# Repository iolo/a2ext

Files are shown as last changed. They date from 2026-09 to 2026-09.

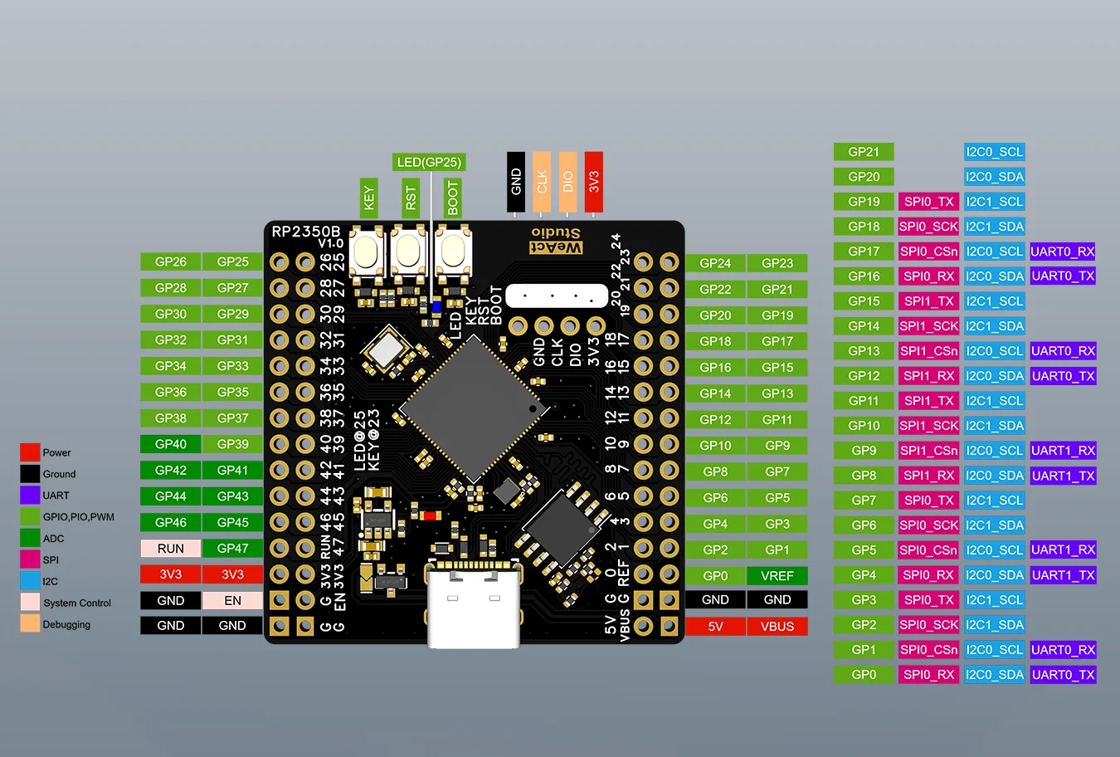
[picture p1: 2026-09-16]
ref/rp2350b-weact.png

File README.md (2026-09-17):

# a2ext

Apple II extension-card prototype built around the **WeAct Studio RP2350B Core
Board V1.0**, with interchangeable VGA and DVI daughterboards. It captures the
full 16-bit address bus, shares a main/auxiliary RAM shadow between firmware
backends, and provides UART and an optional active slot-ROM demo.

**Status: implemented schematic and firmware prototypes; hardware acceptance is
open.** Software tests and all three schematic ERC checks pass. Power sequencing,
bus timing, live capture throughput and monitor operation have not been measured.
DVI and the active demo use experimental 252 MHz clocking, above the RP2350
rating. PCB layout and fabrication files are outside this release.

## Deliverables

| Component | Files |
|---|---|
| Carrier with direct Apple II bus connections | [KiCad project, PDF, BOM and assembly notes](hw/a2ext-carrier/) |
| RGB333 VGA daughterboard | [KiCad project, PDF, BOM and DAC calculations](hw/a2ext-vga/) |
| DVI over HDMI connector | [KiCad project, PDF, BOM and wiring](hw/a2ext-dvi/) |
| Common capture, API and shadow library | [a2ext-lib](fw/a2ext-lib/README.md) |
| Passive/active demonstration | [a2ext-demo](fw/a2ext-demo/README.md) |
| AppleII-VGA renderer port | [a2ext-vga](fw/a2ext-vga/README.md) |
| A2DVI renderer/libdvi port | [a2ext-dvi](fw/a2ext-dvi/README.md) |

[PRD](PRD.md), [implementation plan](PLAN.md), and [progress record](PROGRESS.md)
describe the scope and per-step commits. [GPIO/IDC assignments](hw/pinout.json)
are the shared hardware/firmware pin contract.

## Build and verify

Use Pico SDK/picotool 2.2.0, ARM GCC/newlib and CMake. The active demo additionally
requires ca65/ld65. See [firmware build instructions](fw/README.md) for dependency
revisions, configuration options and flashing.

```sh
cmake -S . -B build/local -DPICO_SDK_PATH=/path/to/pico-sdk \
  -DPICO_TOOLCHAIN_PATH=/path/to/arm-toolchain -DCMAKE_BUILD_TYPE=Release
cmake --build build/local -j4
python3 tools/smoke.py
python3 tools/smoke.py --erc --firmware-from build/local
```

Builds produce `a2ext-demo`, `a2ext-vga` and `a2ext-dvi` ELF/UF2/map files.
The default demo is passive; video targets render host shadow memory at nominal
640x480/60 Hz. `A2EXT_APPLE_MODEL=IIPLUS` selects II/II+ behavior;
`A2EXT_VIDEO_TEST_PATTERN=ON` selects video test patterns;
`A2EXT_DEMO_ACTIVE=ON` opts into the experimental slot responder.

The [verification record](docs/VERIFICATION.md) separates host replay, clean
builds and ERC from unperformed physical tests. Renderer replay writes images
to `build/replay`. [Resource accounting](docs/resources.md) covers PIO, DMA,
clocking, scheduling and SRAM; no full output framebuffer is allocated.

## Hardware preparation and first use

The module has **two 2x15 headers**, not Pico headers. With all power removed,
prepare its GPIO23 button, GPIO25 LED, secondary-memory branch and USB power path:
remove **R16, R19, R14 when fitted, and on-module U2**; leave U7/R13/C23
unpopulated. U2 removal disables USB power; carrier D2 is omitted. Read the
[carrier assembly notes](hw/a2ext-carrier/README.md) before modifying a module;
on-module designators differ from carrier designators.

All 33 host-bus lines connect directly to GPIO2-34, with an optional SYNC jumper.
GPIO40-47 remain on the 3.3 V daughterboard interface. There is no power-off bus
isolation. Slot pin 25 feeds F1/D1 and the module's **5V (H1.2)** input,
labelled `VSYS` on the carrier; **VBUS (H1.1)** is unconnected. USB is data only.
For flashing, remove the card and supply 5 V through a fixture at slot pins
25/26. Do not hot-plug it. The
[power-transition checks](hw/a2ext-carrier/POWER-VALIDATION.md) and
[bench procedure](docs/HARDWARE-VALIDATION.md) remain open.
Use direct daughterboard mating first. The fused slot rail supplies HDMI +5 V.

UART0 is 115200 8N1, 3.3 V, on IDC pins 1 (TX) and 2 (RX), with ground on 16/20.
Send `?` for passive/video diagnostics. Missing slot-7 SYNC does not gate video.
Capture begins before renderer initialization, but it cannot reconstruct earlier
RAM writes. Unknown bank state requires explicit switch initialization and a host
redraw; warm RESET preserves RAM and reacquires switches. The bench guide gives
a repeatable IIe initialization sequence. Active response limitations, including
late replies and reset races, are documented in the library and demo guides.

## Compatibility scope

| Host/output | Implemented software | Validation |
|---|---|---|
| Apple II / II+ | 40-column normal/inverse/flashing text, lores, hires, mixed, pages 1/2 | Host replay and builds; physical not run |
| Apple IIe | Above plus main/aux banking, 80-column, alternate charset, double lores/hires, 80STORE and IOUDIS | Host replay and builds; physical not run |
| VGA | RGB333, 640x480/60, 126 MHz system clock | Replay/build/ERC; DAC/sync/monitor not run |
| DVI | TMDS via PIO1/PWM, 640x480/60, experimental 252 MHz | Replay/build/ERC; signal/clock/monitor not run |
| Active demo | Slot registers/ROM, C800 ownership, UART, IRQ/NMI | Policy/PIO logic/build; physical timing not run |

US enhanced IIe and US II/II+ fonts are bundled. Unenhanced IIe-specific font,
PAL color emulation, Videx/Video7 interfaces, IIc/IIgs, language-card/RamWorks
shadowing, audio, CEC and EDID negotiation are outside the validated scope.
The two video renderers retain their upstream artifact-color palettes.

## Upstream work

This project adapts [a2pico](https://github.com/oliverschmidt/a2pico),
[AppleII-VGA](https://github.com/markadev/AppleII-VGA) through the
[rallepalaveev fork](https://github.com/rallepalaveev/AppleII-VGA), and
[A2DVI-Firmware](https://github.com/ThorstenBr/A2DVI-Firmware), including libdvi.
Original MIT notices are retained alongside the ports. See
[attribution and revisions](docs/ATTRIBUTION.md). Reference trees are kept
separate from the adapted firmware sources.

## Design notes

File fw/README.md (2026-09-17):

# Firmware build and flashing

Three targets share `a2ext-lib`: passive/optional active demo, VGA, and DVI.
These are software-checked prototypes; see [verification](../docs/VERIFICATION.md)
and the open [physical gate](../docs/HARDWARE-VALIDATION.md).

## Dependencies

- Pico SDK **2.2.0**, commit `a1438dff1d38bd9c65dbd693f0e5db4b9ae91779`.
- picotool 2.2.0 for UF2 generation, revision in `dependencies.json`.
- CMake >=3.20, Make or Ninja, ARM GCC/newlib. Validation used GCC 14.2.1.
- ca65/ld65 for `A2EXT_DEMO_ACTIVE=ON`; Python 3 for ROM embedding and checks.
- Host C11 compiler/pthreads for tests; KiCad CLI 10 for schematic checks.

The CMake build rejects a different Pico SDK version. Use the exact dependency
commits in [dependencies.json](dependencies.json) for reproduction. PIO assembly
uses the matching SDK tool. Supply an installed picotool CMake package via
`-Dpicotool_DIR=/path/to/picotool`; otherwise the SDK may download/build its
matching tool. USB stdio is disabled, and UART0 belongs to the a2ext library.
The firmware ports are self-contained and do not build source from `ref/`.

```sh
cmake -S . -B build/local -DPICO_SDK_PATH=/path/to/pico-sdk \
  -DPICO_TOOLCHAIN_PATH=/path/to/arm-toolchain \
  -Dpicotool_DIR=/path/to/picotool -DCMAKE_BUILD_TYPE=Release
cmake --build build/local -j4
```

Run at repository root. The toolchain directory contains `bin/arm-none-eabi-gcc`
and its newlib installation. If the compiler is already on PATH, the explicit
toolchain argument can be omitted. Choose a fresh build directory when changing
SDK/toolchain paths. Outputs are `a2ext-{demo,vga,dvi}.elf`, `.uf2`, and `.elf.map`.

For this workspace's restored toolchain, the verified configuration is:

```sh
cmake -S . -B build/resumed -DPICO_SDK_PATH=/home/iolo/pico-sdk \
  -DPICO_TOOLCHAIN_PATH=/home/iolo/workspace/retro/a2ext/.cache/arm-toolchain/usr \
  -Dpicotool_DIR=/home/iolo/pico-sdk/picotool -DCMAKE_BUILD_TYPE=Release
cmake --build build/resumed -j4
```

## Configuration

| CMake option | Default | Meaning |
|---|---|---|
| `A2EXT_APPLE_MODEL` | `IIE` | `IIE` or `IIPLUS` (also original Apple II); selects banking/font behavior |
| `A2EXT_DEMO_ACTIVE` | `OFF` | Compile 6502 ROM and enable experimental active slot responses; 252 MHz, SRAM execution |
| `A2EXT_VIDEO_TEST_PATTERN` | `OFF` | VGA test chart / DVI color bars while passive capture continues |

VGA/passive demo use 126 MHz. DVI uses 252 MHz to serialize 25.2 MHz pixels;
this exceeds the RP2350 rating and remains unqualified. Firmware does not alter
core voltage. Both video outputs default to 640x480/60 Hz with centered Apple
content. Models are selected explicitly, not auto-detected. See each target's
README for supported features and limitations.

The prepared-module board definition targets RP2350B/ARM and 16 MiB flash. It
omits stock LED/button/SPI/I2C defaults because those pins carry Apple II signals.
Do not substitute the stock WeAct definition. `tools/pinout.py` validates the
header generated from `hw/pinout.json`.

## Verification

```sh
python3 tools/smoke.py
python3 tools/smoke.py --erc --firmware-from build/local
python3 tools/memory_report.py build/local --size-tool /path/to/arm-none-eabi-size
```

The matrix uses fresh build directories and saves logs. It also exercises the
actual renderers on desktop traces, with PPM output under `build/replay`. Tests
never flash the module. UF2 generation is not evidence of hardware operation.

## Flashing procedure

No flashing has been performed in this project session. First complete module
preparation and the fixture power checks. Remove the card from the Apple II
before flashing. USB is data only: on-module U2 and carrier D2 are removed.
Use a current-limited 5 V fixture connected to J1 pin 25 (+5 V) and pin 26 (GND),
with bus signal outputs released. This powers the normal F1/D1/VSYS path.

1. Hold BOOTSEL while applying fixture power (or hold BOOTSEL and pulse module
   RUN with fixture power already on), then release BOOTSEL.
2. Connect USB for data. Confirm the RP2350 boot drive appears; copy exactly one
   selected `.uf2` to it.
   Use the passive demo first, then a video test-pattern build on a fixture.
3. Let the module reboot; verify current draw and released host-bus pins before
   any host connection. UART uses IDC 1/2 at 3.3 V, 115200 8N1; no USB console.
4. After electrical qualification, perform the host/timing tests in the bench
   guide. Do not enable active mode merely because the passive image boots.

To recover an unsuitable firmware image, disconnect the host and repeat BOOTSEL
with a known passive image. Apple /RES does not reset the RP2350; module RUN does.
Archive the ELF, map, UF2 hash, options, dependency revisions and measurements
for each tested hardware configuration.

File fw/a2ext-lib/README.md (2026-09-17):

# a2ext-lib interface

Call `a2ext_init()` once on core 0 before starting capture or other cores. It
releases every Apple II bus pin, initializes UART0 at 115200 8N1, and enables
reset observation. It never configures a default LED or button. Active data
output is disabled by default.

Call capture start/next/stop/stats on one owning core (normally core 1). The
capture engine owns PIO0 SM0, two claimed DMA channels, and DMA IRQ1 on that
core. `a2ext_next_cycle` is nonblocking and returns an atomic address/data/RWB/
select sample. Select booleans mean asserted. Read-cycle data is observational
only; the current sampling window guarantees no claim about CPU read values.

`getaddr/getdata` return fields of the last successfully returned cycle; they
do not consume or read live GPIOs. `has_cycle` is false before the first sample.
Prefer the atomic cycle interface. Getters belong to the capture owner, not
arbitrary concurrent consumers. Watch `stats.epoch`: start, stop, FIFO stalls,
and unread-block overwrite break continuity. Overflow recovery discards queued
samples and resynchronizes on PHI0; shadow users must invalidate their state.

`irq(true)` and `nmi(true)` assert low; false releases the line. The output
latch is always zero. Apple reset assertion releases both interrupt outputs.
These pins connect directly to the host, whose pull-ups complete this interface.

Register reset, UART receive, and optional composite SYNC callbacks on core 0.
Call `a2ext_poll` there regularly. IRQs enqueue events; poll dispatches at most
32 per call. The bounded queue counts dropped events via `callback_drops`.
Callback loss must be reported by the application. Callbacks never run in
capture context, and must not perform long blocking work when rendering video.

SYNC is slot-7 composite sync, not the CPU clock. Registration counts falling
edges; counter 0 or NULL disables it. An absent SYNC signal does not affect
capture or video timing. Reset callbacks receive true on assertion and false
on release. UART receive passes a byte zero-extended to the requested uint32_t
callback argument. `send` blocks until UART TX accepts a byte; do not call it
from the capture/response core.

Enable the experimental responder with `a2ext_slot_enable(handler)` on the
bus core, then call `a2ext_slot_poll()` continuously there. It owns PIO2 SM0
(27 words) and PIO0 SM1 (a separate 3-word delayed sample). The handler sees
selected reads early and writes after the delayed sample. Return true with
`*reply` set to answer a read; false leaves the data bus released. The default
remains passive. Disable releases the data pads before stopping either SM.

`try_putdata` accepts requests only inside an eligible read callback, with
PHI0 and reset high. Acceptance means queued, not acknowledged by the 6502.
PIO matches a 24-bit cycle tag and rejects stale replies. C800 requires prior
local Cnxx selection; CFFF or another slot's Cnxx access releases ownership.
FIFO overflow or early/late address mismatch disables responses and latches
`slot_faulted`; re-enable explicitly to recover. Do not stop a core or PIO with
a debugger while connected to a running host.

This is an experimental response implementation: software tests do not prove
6502 setup/hold timing. Falling PHI0 can race the final enable instructions;
logical release takes up to four PIO cycles after the internally observed
edge, plus input synchronization and board propagation. Reset prevents new
CPU requests but does not asynchronously cancel an already queued reply.
Callbacks may have side effects even when their reply misses the deadline;
protocols needing acknowledged reads need a completion mechanism. Qualify
these limitations with a bus fixture before enabling active mode on a host.

## Optional shadow model

`a2ext_shadow.h` owns 128 KiB RAM plus 16 KiB validity. Select IIe or II/II+
explicitly at initialization. Feed each cycle and capture epoch from the capture
core; do not also apply deferred reset callbacks. /RES is sampled with each
cycle. Reset retains observed RAM but marks switches unknown until accesses
reacquire them. Startup and stream loss similarly require switch reacquisition;
unknown-bank writes are discarded. This can delay a useful display until the
host initializes its switches and redraws. Reading RAM alone cannot recover it.

RAM writes below C000 are tracked. ALTZP controls 0000-01FF; AUXWRITE controls
0200-BFFF except 80STORE's page-1 text and HIRES-dependent graphics overrides.
80STORE suppresses displayed page 2. IIe 80COL/ALTCHAR/IOUDIS/AN3 are tracked; II/II+
ignore these. Language-card RAM, RamWorks, IIc/IIgs extensions, and Videx are
not modeled. IOUDIS must be observed on before AN3 changes DHIRES.
`shadow_byte` reports unknown bytes; `shadow_copy` substitutes zero.
Atomic readers can take a frame copy while capture continues, with possible
tearing. No API claims a coherent host framebuffer snapshot.

Banking reference: [Apple IIe Reference Manual, chapter 4](https://mirrors.apple2.org.za/Apple%20II%20Documentation%20Project/Computers/Apple%20II/Apple%20IIe/Manuals/Apple%20IIe%20Technical%20Reference%20Manual.pdf).

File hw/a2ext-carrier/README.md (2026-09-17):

# a2ext-carrier schematic prototype

Open `a2ext-carrier.kicad_pro` in KiCad 10. Symbols are project-local and embedded
in the schematic. `BOM.csv` lists component values; footprints not yet specified
are deliberate because PCB layout is out of scope. `connections.json` is the
generated connectivity contract, checked against KiCad's exported netlist.

Revision 0.5 uses A4 landscape with 1.524 mm pin names, wire labels, and values;
pin numbers are 1.27 mm and references/notes are 1.778 mm. Symbols and notes
are rearranged for printing at actual size; electrical connections are unchanged.

**Status: schematic draft, not electrically qualified.** ERC checks connectivity,
not bus timing, power sequencing, module thermals, or Apple II compatibility.

## Module and connections

M1 represents both WeAct V1.0 headers. Pin numbers `H1.n` and `H2.n` refer to
the vendor schematic, not arbitrary carrier header numbering. Do not substitute
a Pico 2 or Clintech module. See the module drawing for orientation.

Prepare the module with power disconnected: remove R16 (KEY/GPIO23), R19
(LED/GPIO25), R14 (secondary chip select), and **on-module U2** (the vendor's
unidentified VBUS-to-5V power-path device). Leave secondary memory U7/R13/C23
unpopulated. Removing U2 disconnects USB VBUS from the module supply; do not
bridge its vacated input/output pads. Carrier D2 is removed and M1 H1.1 (VBUS)
is unconnected. Inspect and continuity-test these modifications. USB is for
data only and cannot power the prepared card.

J1 follows the PRD's counter-clockwise slot numbering. /INT and /DMA chains
pass through. Unused negative supplies, +12V, /RDY, /DMA, /INH, and auxiliary
clocks are not connected. JP1 defaults open: close it only when motherboard
documentation confirms composite SYNC on slot 7 pin 19. UART0 and all 13 general
daughterboard GPIOs are on J2. /RES is sensed separately from module RUN.

## Direct bus and power

Revision 0.5 retains direct connections for all 33 bus signals to GPIO2-34,
with JP1 in the optional SYNC path. Wire labels use Apple II signal names
(`A0`, `D0`, `IOSEL_N`, etc.), `UART_TX`/`UART_RX`, and daughterboard names
such as `IDC03_GPIO35`. `_N` means active low; UART direction is from the
carrier's perspective. M1 shows the physical GPIO names and WeAct header
contacts; J2 shows pin functions alongside its contact numbers. Matching
wire labels identify the same electrical net. No bus switches, supervisors,
or BUS_GOOD/BUS_OE_N control circuit remain. GPIO40-47 stay on the 3.3 V
daughterboard interface. Firmware
must drive IRQ/NMI low or release them; the host supplies their pull-ups.

RP2350 fault-tolerant digital inputs support 5 V with IOVDD powered at 3.3 V.
The direct connection provides no protection against a live 5 V bus with an
unpowered module. All operating power comes from the slot supply. Flash with
the card removed from the host, using a 5 V fixture at J1 pins 25/26 and USB
for data only; do not hot-plug the card. Measure startup/shutdown
and brownout behavior using the [power-validation procedure](POWER-VALIDATION.md).

R4 retains the module RUN pull-up. RUN resets M1 but does not disconnect bus
pins; Apple /RES remains a separate input.

The power path is `J1.25 (+5V_SLOT) -> F1 -> D1 -> VSYS -> M1 H1.2`.
The WeAct module labels H1.2 **5V**; it feeds the regulator input and serves the
same function as Pico's VSYS. H1.1 is **VBUS**, and stays unconnected on the
carrier. D1 is retained as reverse-current protection, with its anode toward
F1 and cathode toward VSYS. C9 decouples VSYS. F2 feeds +5V_DB from the fused
slot rail before D1. J2 power pins are outputs, not auxiliary inputs.

Initial allocation: at most 400 mA for carrier/module plus 100 mA for the
daughterboard from the slot branch, subject to the actual host's available
budget and PTC derating. This is a design ceiling, not a measured consumption
or a fuse trip-current guarantee. The module regulator's part number/current
rating is unspecified in the vendor drawing; reserve the 3.3 V daughterboard
pin for light loads until that rating and module temperature are established.

## Checks and outstanding work

```sh
python3 tools/pinout.py
python3 tools/check_schematics.py a2ext-carrier
```

Run from the repository root. Regenerate explicitly with
`python3 tools/schematics.py carrier`; review changes before replacing manual
edits. Export the PDF with `kicad-cli sch export pdf`.

Physical release requires power-transition, supply/thermal, and bus timing
measurements. ERC does not establish the WeAct module's supply ramp behavior.

Sources: vendor module files in `ref/WeActStudio.RP2350BCoreBoard/HDK/`,
[RP2350 datasheet](https://datasheets.raspberrypi.com/rp2350/rp2350-datasheet.pdf).

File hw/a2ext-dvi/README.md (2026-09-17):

# a2ext-dvi

Revision 0.2 uses A4 landscape with enlarged text: 1.524 mm pin names,
wire labels and values, 1.27 mm pin numbers, and 1.778 mm references/notes.
The revised layout preserves all electrical connections.

Passive DVI video daughterboard using an HDMI Type A connector and the PRD's
270 ohm series resistor network. Open the KiCad 10 project; symbols are local.
The abstract SH pin represents all connector shell contacts. Confirm the exact
HDMI-SWM-19 mechanical drawing and pad numbering before any PCB work.

| Lane | Positive GPIO / IDC | Negative GPIO / IDC | HDMI contacts |
|---|---|---|---|
| D0 | 36 / 4 | 37 / 5 | 7 / 9 |
| D1 | 38 / 6 | 39 / 7 | 4 / 6 |
| D2 | 40 / 8 | 41 / 9 | 1 / 3 |
| Clock | 42 / 10 | 43 / 11 | 10 / 12 |

Each conductor has a 270 ohm, 1% resistor. Shields, pin 17, shell, and both IDC
ground contacts share GND. Pin 18 receives the carrier's fused +5V_DB supply;
there is no additional series diode drop on this board. C1 decouples that rail.
UART, RUN, 3.3 V power, GPIO35/44-47, DDC, HPD, CEC, and utility are unused.

The bundled libdvi program uses the lower GPIO for the positive conductor when
`invert_diffpairs=false`. Use PIO1 base 16 and 64-bit mask helpers. Its clock
generator uses the shared PWM slice for even/odd GPIO42/43. This is the
reference's resistor-driven signaling approach, not a claim of HDMI compliance.

Initially use direct carrier mating. No ribbon cable length is qualified.
Validate a fixed 640x480 timing mode, pair polarity, eye/edge quality, connector
+5 V, and lock on multiple monitors with a real board. No EDID negotiation or
hotplug handling is implemented by this schematic. Carrier power comes from
the slot input (or an off-host fixture at that input); USB is data only.

Validation so far: ERC and named-net export checks. Firmware and physical
TMDS tests are pending. From the repository root:

```sh
python3 tools/schematics.py dvi
python3 tools/check_schematics.py a2ext-dvi
```

References: `ref/A2DVI` v5.x hardware and
`ref/A2DVI-Firmware/libraries/libdvi/dvi_serialiser.{c,pio}`.

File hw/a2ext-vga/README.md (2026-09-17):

# a2ext-vga

Revision 0.2 uses A4 landscape with enlarged text: 1.524 mm pin names,
wire labels and values, 1.27 mm pin numbers, and 1.778 mm references/notes.
The revised layout preserves all electrical connections.

KiCad 10 schematic and project-local symbols for a passive 9-bit VGA
daughterboard. J1 follows the common IDC20 pinout. J2 is a female DE-15HD;
its abstract SH pin represents the connector shell. Select the connector's
exact shell/mounting pad numbers when a PCB is designed.

GPIO35-43 are R0-R2, G0-G2, B0-B2. GPIO44/45 are HSYNC/VSYNC. UART, GPIO46/47,
power, and RUN are unused. Both IDC ground contacts connect to VGA grounds and
shell. DDC, ID, and pin 9 power are unconnected, as specified in the PRD.

Each color has 2 kohm, 1 kohm, and 500 ohm resistors for bits 0, 1, and 2.
Use 1% tolerance. With a 75 ohm monitor load and ideal 3.3 V GPIO outputs:

`Vout = 3.3 * (b0/2000 + b1/1000 + b2/500) / (1/75 + 1/2000 + 1/1000 + 1/500)`

The eight nominal levels are 0, 0.0980, 0.1960, 0.2941, 0.3921, 0.4901,
0.5881, and 0.6861 V. Full-scale current is 9.15 mA per color; the MSB GPIO
supplies about 5.23 mA. Firmware pad drive settings must support this load;
start with 8 mA drive and verify voltage and edge quality on hardware. Real
GPIO output impedance changes these ideal values.

R10/R11 are 47 ohm series resistors on sync. Use direct mating to the carrier
for initial qualification; an IDC ribbon cable has no validated length.

Validation: KiCad ERC and exported named-net checks; physical levels and
640x480 timing are not yet tested. Run from the repository root:

```sh
python3 tools/schematics.py vga
python3 tools/check_schematics.py a2ext-vga
```

Design references: PRD resistor network and the bundled A2VGA2 schematic.

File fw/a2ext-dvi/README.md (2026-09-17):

# DVI firmware

Port of the bundled A2DVI-Firmware renderer and its libdvi serializer. Original
MIT notices remain in the source, LICENSE, and libdvi/LICENSE. Text, lores,
hires, mixed, page switching, 80-column, double-lores and double-hires paths
consume frame copies from the common main/aux shadow model.

PIO1 base 16 drives the three TMDS data pairs, PWM GPIO42/43 drives the clock,
and six DMA channels feed the serializer through DMA IRQ0 on core 0. Core 1
owns passive bus capture. Output is 640x480 at 60 Hz, with 560x384 Apple content
and 48-line top/bottom borders. Eight 3840-byte TMDS buffers are allocated;
there is no full RGB framebuffer. No SYNC input or EDID negotiation is needed.

252 MHz is experimental and above the RP2350's rated frequency. Firmware does
not raise core voltage. Build success is not evidence of physical stability,
monitor lock, or reliable capture under rendering load. Qualification requires
the carrier power gate, timing measurements and sustained host/monitor tests.

`A2EXT_APPLE_MODEL=IIE` (default) uses an enhanced US font and IIe banking;
`IIPLUS` uses II/II+ behavior. `A2EXT_VIDEO_TEST_PATTERN=ON` produces color bars
while capture continues. UART `?` reports capture status. Menus, Videx, Video7,
IIgs, buttons/LEDs, custom configuration registers and alternate video timings
from the reference are outside this port's supported interface.

Adaptations: high-GPIO 64-bit masks, PIO base 16, carrier pair polarity, normal
Pico SDK RAM sections instead of the upstream custom linker-copy scheme,
384-line content window, fixed configuration, common capture/shadow, and
finite-frame entry point. TMDS patterns retain the upstream color choices;
VGA and DVI artifact colors need not be numerically identical.

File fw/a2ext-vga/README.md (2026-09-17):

# VGA firmware

Port of the bundled rallepalaveev AppleII-VGA renderer (MIT, see LICENSE).
Uses shared passive capture/shadow on core 1 and frame snapshots/rendering on
core 0. PIO1 base 16 generates RGB333 and sync; DMA IRQ0 feeds eight scanline
buffers. Capture uses PIO0 and DMA IRQ1. No full RGB framebuffer is allocated.

Default output is 640x480 at 60 Hz, centered 560x384 Apple content. Supports
40-column text, lores, hires, mixed mode and page selection; IIe adds 80-column,
alternate charset, double lores and double hires. Defaults to enhanced US IIe
font; `A2EXT_APPLE_MODEL=IIPLUS` selects II/II+ font and bank behavior. Videx,
Video7 control extensions and PAL color emulation are not enabled.

`A2EXT_VIDEO_TEST_PATTERN=ON` renders the upstream test chart while capture
continues. UART `?` reports capture losses and known soft switches. Initial
unobserved bytes render as zero; reset/stream loss may require host switch
initialization and redraw. Physical timing, DAC levels, sustained throughput,
and display correctness are not yet qualified.

Port changes: GPIO35-45 mapping/base 16, RGB channel bit reversal at DMA
submission (including precomputed hires patterns), valid OUT count for nine
pins, 8 mA DAC drive, shared shadow snapshots and finite frame entry point.

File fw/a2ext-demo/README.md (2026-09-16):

# Demo

Default builds passively count bus cycles. UART0 is 115200 8N1 on IDC pins
1/2 with 3.3 V levels. Send `?` for capture/overflow/callback-drop counters;
reset transitions are reported. No daughterboard or slot-7 SYNC is required.

`-DA2EXT_DEMO_ACTIVE=ON` builds the experimental a2pico-derived slot ROM and
register demo. Requires ca65/ld65; runs from SRAM at 252 MHz (above the RP2350
rating). Qualify carrier power and response timing before use. Read the
limitations in `../a2ext-lib/README.md`. No hardware operation is claimed.

The 4096-byte ROM contains seven slot pages and C800 code. After qualification,
`PR#n` enters the terminal demo in slot n. Register offset 0 transfers a byte;
offset 1 reports bit 6 RX-ready and bit 7 TX-ready. Writing offset 1 releases
IRQ/NMI. UART ESC asserts IRQ and Ctrl-N asserts NMI. The bounded inter-core
FIFOs can drop UART input when full; this is a demonstration, not a reliable
serial adapter. Reset releases IRQ/NMI and C800 ownership.

`firmware.S` and `firmware.cfg` derive from Oliver Schmidt's a2pico demo;
original MIT notices are preserved. The banner is adapted to a2ext.

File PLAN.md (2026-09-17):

# a2ext implementation plan

**Execution rule:** After each numbered implementation step, update `PROGRESS.md`
with changes, validation results, and blockers, then commit that step's changes
together with the progress update. Include only task-related changes. Record
partial or blocked work honestly; a commit does not imply completion.

## Summary and agreed scope

Build a WeAct Studio RP2350B Core Board carrier, VGA and DVI daughterboard
schematics, a shared firmware library, and demo/VGA/DVI firmware.

Target Apple II/II+ and IIe, including IIe auxiliary-memory video modes. Deliver
KiCad schematics, BOMs, documentation, and reproducible firmware builds. PCB
routing and fabrication outputs are excluded; physical validation remains a
separately recorded acceptance gate.

Use the bundled reference projects as porting sources, preserving attribution
and licenses. Keep their source trees unchanged.

Approved revision (2026-09-17): use direct bus connections, following the
RP2350 reference designs. Remove the CB3T switches and their supervisors,
BUS_GOOD/OE control, and local support components. This supersedes the earlier
isolation refinement. Keep power-transition measurements and document installed
slot-only power operation. Revision 0.3 removes D2 and leaves module VBUS NC;
slot power feeds F1/D1 and H1.2 (5V, equivalent to VSYS). On-module U2 stays
removed to disable USB power. Off-host flashing uses fixture power and USB data.

## 1. Resolve the hardware and firmware contracts

1. Update the PRD to identify the WeAct module and correct its connector
   description using the supplied schematic and dimensions.
2. Correct RX on IDC pin 2, `TMDS` spelling, `uint8_t`, and the DVI framebuffer
   description. Add the demo firmware to the expected outputs.
3. Record removal of the module's GPIO23 button connection and GPIO25 LED load
   through R16/R19, as approved. Verify these designators against the actual
   module revision. Leave optional secondary flash/PSRAM unpopulated because
   its chip select shares GPIO0.
4. Establish this GPIO assignment:

   | Signals | GPIOs |
   |---|---|
   | UART TX / RX | 0 / 1 |
   | A0-A15 | 2-17 |
   | D0-D7 | 18-25 |
   | RWB | 26 |
   | /DEVSEL, /IOSEL, /IOSTRB | 27, 28, 29 |
   | PHI0, /RES | 30, 31 |
   | /IRQ, /NMI, optional composite SYNC | 32, 33, 34 |
   | Daughterboard general-purpose signals | 35-47 |

5. Define IDC pins 1/2 as TX/RX; pins 3-15 as GPIO35-47; pin 16 as an additional
   ground; pin 17 as 3.3 V; pin 18 as module RUN; pins 19/20 as protected
   5 V/ground. This provides 13 additional GPIOs, accounting for all 33 Apple II
   bus signals.
6. Allocate PIO0 to bus capture with GPIO base 0 and PIO1 to video with GPIO
   base 16. Reserve PIO2 for active slot responses. Validate instruction,
   state-machine, DMA, and timing budgets before completing the schematics.
   RP2350 PIO blocks address 32 GPIOs at a time through these base selections.

**Exit criterion:** one reviewed pin/resource table shared by schematics,
firmware constants, and documentation.

## 2. Complete the three hardware designs

7. Create the carrier under `hw/a2ext-carrier`:
   - Use project-local symbols for the WeAct module and correctly numbered
     Apple II slot.
   - Preserve interrupt/DMA chain connections and specified unused slot pins.
   - Keep Apple /RES sensing separate from module RUN.
   - Implement /IRQ and /NMI as assert-low/release outputs.
   - Document slot-only power, USB power disconnection, reverse-current protection,
     decoupling, and daughterboard power budgets.
8. Validate startup, shutdown and brownout behavior for the approved direct-bus
   circuit. Document the powered-IOVDD requirement and USB operating restrictions.
   Keep ADC-capable GPIO40-47 exclusively on the 3.3 V daughterboard interface.
   Do not declare hardware ready if sequencing remains unresolved.
9. Create the VGA schematic under `hw/a2ext-vga`:
   - Assign R0-R2 to GPIO35-37, G0-G2 to GPIO38-40, B0-B2 to GPIO41-43.
   - Assign HSYNC/VSYNC to GPIO44/45.
   - Implement the specified resistor DACs and sync resistors; calculate
     output levels into a 75 ohm termination.
10. Create the DVI schematic under `hw/a2ext-dvi`:
    - Assign D0 +/- to GPIO36/37, D1 +/- to GPIO38/39, D2 +/- to GPIO40/41,
      and clock +/- to GPIO42/43.
    - Use the reference's resistor-driven TMDS circuit and verify polarity
      against serializer configuration.
    - Keep audio, CEC, and EDID negotiation outside v1.
    - Document direct daughterboard mating as the baseline; ribbon-cable
      operation requires separate signal-integrity validation.

**Exit criterion:** all three schematics pass ERC with reviewed exceptions and
include BOMs, exported PDFs, connector tables, and assembly notes.

## 3. Implement the shared library and demo

11. Establish CMake/Pico SDK builds and a WeAct board definition. Pin dependency
    revisions and produce ELF, UF2, and map files for all three firmware
    targets. Place the common library in `fw/a2ext-lib`.
12. Implement passive capture first:
    - Sample full addresses, data, RWB, and slot selects using PHI0-qualified
      timing.
    - Transfer captured cycles through DMA into bounded buffers.
    - Expose overflow counters and mark shadow state invalid after capture
      loss.
    - Keep timing-critical capture independent of rendering and UART callbacks.
13. Define the library interfaces:
    - Preserve requested API names and correct their types.
    - Add an atomic bus-cycle interface containing address, data, direction,
      and selection flags; define getaddr/getdata against the same latched
      cycle.
    - Restrict putdata to an eligible, current slot-read transaction; reject
      late responses and release the bus at cycle end.
    - Default to passive mode; explicitly enable slot response handling.
    - Use UART0 at 115200, 8N1. Retain the requested receive callback signature,
      with the byte in its low eight bits.
    - Define SYNC callbacks as counting composite-sync pulses, not PHI0 cycles.
      Missing slot-7 SYNC must not prevent operation.
14. Add active slot responses and port the a2pico demo into `fw/a2ext-demo`.
    Exercise slot registers/ROM, reset reporting, UART, IRQ, and NMI. Enforce
    C800 ownership and CFFF release; /IOSTRB alone must not enable data output.
15. Implement optional shared video shadowing: main/auxiliary memory tracking,
    video soft switches, page selection, and reset state. Begin capture early,
    document incomplete initial shadow contents, and avoid clearing shadow RAM
    merely because Apple RESET occurs.

**Exit criterion:** demo builds and automated bus traces validate capture,
slot ownership, and shadow-state behavior.

## 4. Port VGA, then DVI

16. Port AppleII-VGA rendering into `fw/a2ext-vga`, replacing its bus interface
    with the common library. Start with test patterns, then add 40-column text,
    lores, hires, mixed mode, page switching, and IIe extended modes.
17. Port A2DVI-Firmware into `fw/a2ext-dvi`, retaining its renderer and PIO/libdvi
    serializer approach. Adapt GPIO-base handling and remove
    transceiver-specific capture code. Use the shared shadow model.
18. Default both outputs to 640x480 at approximately 60 Hz. Give bus capture
    priority over rendering and diagnostics. Document and validate the DVI
    clock configuration, including any above-rated operation inherited from
    the reference.

**Exit criterion:** both backends render the same replayed Apple II video states
without capture overflow or resource conflicts.

## 5. Verify and package

19. Automate clean builds, pin-allocation checks, KiCad ERC, and trace-based tests
    covering full-address capture, consecutive cycles, reset, overflow
    recovery, selected/unselected reads, late responses, C800 ownership,
    II/II+ video modes, IIe banking, 80-column, double-lores, double-hires,
    missing SYNC, and simultaneous capture/rendering load.
20. Publish hardware validation procedures for power sequencing, bus loading,
    response timing, interrupt release, VGA voltage/timing, and DVI stability.
21. Complete the README with build/flashing instructions, module modifications,
    compatibility matrix, resource allocation, upstream attribution, and
    validation results. Clearly distinguish automated verification from
    measurements requiring assembled hardware.

## Technical references

- Local module schematic, dimensions, and pinout:
  `ref/WeActStudio.RP2350BCoreBoard/HDK/`.
- [RP2350 datasheet](https://datasheets.raspberrypi.com/rp2350/rp2350-datasheet.pdf):
  PIO GPIOBASE, electrical ratings, and GPIO pad types.
- [Raspberry Pi 5 V tolerance qualification](https://www.raspberrypi.com/news/rp2350-a4-rp2354-and-a-new-hacking-challenge/):
  IOVDD must remain powered when 5 V is applied to GPIO.

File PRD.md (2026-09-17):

# a2ext

GOAL: General purpose Apple II Extension Card using the WeAct Studio RP2350B Core Board and daughter boards.

- Adapt a2pico's general hardware concept to RP2350B.
- Snoop all address range(A0..A15) like AppleII-VGA and A2DVI.
- Utilize 48 GPIOs of RP2350B instead of complex multiplexing for insufficient GPIO of RP2040/RP2350.
- Delegate specific functions to daughter boards, with a 20pin IDC connector for daughter boards rather than a single monolithic design.

EXPECTED OUTPUT:

1. a2ext-carrier kicad schematic and docs in hw/a2ext-carrier
2. a2ext-vga kicad schematic and docs in hw/a2ext-vga
3. a2ext-dvi kicad schematic and docs in hw/a2ext-dvi
4. a2ext-lib common library for a2ext-carrier daughter board firmware in fw/a2ext-lib
5. a2ext-vga firmware in fw/a2ext-vga
6. a2ext-dvi firmware in fw/a2ext-dvi
7. a2ext-demo firmware in fw/a2ext-demo

## a2ext-carrier

The carrier accepts the WeAct Studio RP2350B Core Board V1.0 documented in
`ref/WeActStudio.RP2350BCoreBoard/HDK/`. Use its two 2x15, 2.54 mm pitch
headers (60 contacts total), not Pico/Pico 2 headers. These expose GPIO0..47
alongside power, reference, enable, and RUN contacts. The module schematic
specifies a 41.4 mm x 41.1 mm board; use the supplied dimension drawing and
STEP model for header placement and USB/button access.

Initial compatibility: Apple II/II+ and IIe, including IIe auxiliary-memory
video modes. Deliver schematics, BOMs, documentation, and firmware; PCB layout
and fabrication files are outside this release.

### Required WeAct module preparation

Use the V1.0 schematic as the reference and check the populated module revision
before changing components. With all power removed:

- Remove R16 (0 ohm) to disconnect GPIO23 from SW3 (KEY), its 5.1 kohm pull-up
  R18, and its associated protection/capacitor network. GPIO23 will carry D5.
- Remove R19 (5.1 kohm) to disconnect the U8 user LED from GPIO25. GPIO25 will
  carry D7. The separate power LED is unaffected.
- Leave U7 (secondary flash/PSRAM) and its optional R13/C23 unpopulated; remove
  R14 (0 ohm), if fitted, to isolate GPIO0 from the FLASH2_SS branch. UART TX
  must not toggle a secondary memory chip select or inherit its pull-up.
- Remove on-module U2 (the vendor's unidentified VBUS-to-5V power-path device).
  This disables USB power. Carrier D2 is omitted and module H1.1 (VBUS) is NC.
  Slot pin 25 feeds F1/D1 and module H1.2 (marked 5V, the VSYS-equivalent input).
  D1 is retained for reverse-current protection; USB is data only.
- Check for opens across the removed resistor pads and shorts to neighboring
  pads before installation. Pressing KEY must no longer connect GPIO23 to GND;
  GPIO25 must no longer connect to U8 through R19.

BOOTSEL, RUN/reset, primary flash, USB data (with external power), and SWD remain usable. The firmware must
not initialize GPIO25 as an LED or GPIO23 as a button. Never fit an unprepared
module: KEY could otherwise pull an Apple II data line low.

```
Apple II Peripheral Slot <--(50pin Edge Connector)--> RP2350B <--(20pin IDC Connector)--> daughter board
```

1. snoops Apple II BUS signals with RP2350B PIO state machines
2. (optional) makes a shadow copy of RAM
3. provides a 20pin IDC connector for daughter boards.

RP2350B digital fault-tolerant pads accept 5 V only with IOVDD powered to
3.3 V; ADC-capable pads do not share that rating. Approved revision 0.2 connects
the bus directly, removing the earlier isolation/control circuit. Use slot power
exclusively. For off-host USB flashing, power the card from a fixture at slot
pins 25/26; USB does not supply power.
Preserve full parallel address/data wiring; do not multiplex the Apple II bus
to save GPIOs. Power-transition measurements remain open.

Required Apple II bus signals required by RP2350B:

- D0..D7 : read/write
- A0..A15 : read only
- RWB : read only (1 for CPU read, 0 for CPU write)
- /DEVSEL : read only (0 on CPU access $C0n0..$C0nF; n=slot+8=9..F for slots 1..7)
- /IOSEL : read only (0 on CPU access $Cn00..$CnFF; N=slot=1..7)
- /IOSTRB : read only (0 on CPU access $C800..$CFFF)
- /RES : read only
- /IRQ : write only
- /NMI : write only
- PHI0 : read only, bus-cycle timing (slot pin 40)
- SYNC : read only, composite video sync (slot 7 pin 19; motherboard-dependent)

## wiring

### Apple II slot (50-pin edge connector) <-> WeAct RP2350B module (two 2x15 headers)

The slot symbol uses counter-clockwise numbering, with pin 1 at the upper
left: 1–25 run down the left side and 26–50 run back up the right side.
Opposing contacts are 1/50, 2/49, through 25/26, matching the
[slot reference](ref/a2slot.png) rotated 180 degrees.

```text
 1 /IOSEL  ┌─────────┐  50 +12V
 2 A0      │         │  49 D0
 3 A1      │         │  48 D1
   ...     │         │     ...
24 /DMAOUT │         │  27 /DMAIN
25 +5V     └─────────┘  26 GND
```

* Pin assignments are defined in [hw/pinout.json](hw/pinout.json).
  Address/data/control inputs GPIO2..31 fit PIO GPIO base 0.
  All 33 Apple II bus connections use GPIO2..34; GPIO40..47 are reserved
  for the 3.3 V daughterboard interface, not 5 V Apple II signals.

- 1 /IOSEL --> GPIO 28
- 2 A0 --> GPIO 2
- 3 A1 --> GPIO 3
- 4 A2 --> GPIO 4
- 5 A3 --> GPIO 5
- 6 A4 --> GPIO 6
- 7 A5 --> GPIO 7
- 8 A6 --> GPIO 8
- 9 A7 --> GPIO 9
- 10 A8 --> GPIO 10
- 11 A9 --> GPIO 11
- 12 A10 --> GPIO 12
- 13 A11 --> GPIO 13
- 14 A12 --> GPIO 14
- 15 A13 --> GPIO 15
- 16 A14 --> GPIO 16
- 17 A15 --> GPIO 17
- 18 RWB --> GPIO 26
- 19 SYNC --> GPIO 34 (slot 7 only; motherboard-dependent)
- 20 /IOSTRB - GPIO 29
- 21 /RDY - N/C
- 22 /DMA - N/C
- 23 /INTOUT - 28 /INTIN
- 24 /DMAOUT - 27 /DMAIN
- 25 +5V_SLOT -- F1 / D1 (SS14) --> VSYS --> module H1.2 (5V); H1.1 (VBUS) N/C
- 26 GND --- GND; 26 GND --(100n cap.)-- 25 +5V
- 27 /DMAIN - 24 /DMAOUT
- 28 /INTIN - 23 /INTOUT
- 29 /NMI <--> GPIO 33 (assert low/release; host pull-up)
- 30 /IRQ <--> GPIO 32 (assert low/release; host pull-up)
- 31 /RES --> GPIO 31 (input only)
- 32 /INH - N/C
- 33 -12V - N/C
- 34 -5V - N/C
- 35 COLORREF - N/C
- 36 7M - N/C
- 37 Q3 - N/C
- 38 PH1 - N/C
- 39 USER1 - N/C
- 40 PHI0 --> GPIO 30
- 41 /DEVSEL --> GPIO 27
- 42 D7 <--> GPIO 25
- 43 D6 <--> GPIO 24
- 44 D5 <--> GPIO 23
- 45 D4 <--> GPIO 22
- 46 D3 <--> GPIO 21
- 47 D2 <--> GPIO 20
- 48 D1 <--> GPIO 19
- 49 D0 <--> GPIO 18
- 50 +12V - N/C

### 20pin IDC Connector <-> RP2350B

The 2x10 IDC header uses odd/even numbering: pins 1 and 2 are opposite
each other, followed by 3 and 4, through 19 and 20. TX/RX are on pins 1/2, VCC/GND are on pins 19/20.

```
   +-------+
TX | 1   2 | RX
   | 3   4 |
   | 5   6 |
   ...
5V | 19 20 | GND
   +-------+
```

The UART signals are named from the carrier's perspective (3.3 V logic).
Pin 18 resets the module through RUN and is separate from Apple II /RES.
Daughterboards may assert RUN low with an open-drain output; never drive it high.

| IDC pin | Carrier signal | GPIO |
|---|---|---|
| 1 | TX | 0 |
| 2 | RX | 1 |
| 3 | GPIO35 | 35 |
| 4 | GPIO36 | 36 |
| 5 | GPIO37 | 37 |
| 6 | GPIO38 | 38 |
| 7 | GPIO39 | 39 |
| 8 | GPIO40 | 40 |
| 9 | GPIO41 | 41 |
| 10 | GPIO42 | 42 |
| 11 | GPIO43 | 43 |
| 12 | GPIO44 | 44 |
| 13 | GPIO45 | 45 |
| 14 | GPIO46 | 46 |
| 15 | GPIO47 | 47 |
| 16 | GND | — |
| 17 | +3V3 output | — |
| 18 | RUN (active low) | — |
| 19 | protected +5V_DB output | — |
| 20 | GND | — |

There are 13 general-purpose daughterboard GPIOs in addition to TX/RX. GPIO46/47
are spare for VGA, and GPIO35/44..47 are spare for DVI. All daughterboard signal
pins use 3.3 V logic; in particular, GPIO40..47 are not 5 V-tolerant pads.
Use direct mating initially; ribbon-cable operation requires separate validation.

## a2ext-vga

a2ext-carrier daughterboard for VGA video output.

- used with a2ext-vga firmware.
- based on [A2VGA2 by rallepalaveev](https://github.com/rallepalaveev/AppleII-VGA/tree/main/A2VGA2),
  which is based on [AppleII-VGA](https://github.com/markadev/AppleII-VGA)

1. Read red, green, blue bits from a2ext-carrier IDC20 connector.
2. Convert to analog RGB using 3-bit weighted resistor DACs.
3. Output VGA signals through a female VGA connector.

### VGA (DE-15HD female) <--> a2ext-carrier 20pin IDC Connector

- 1 R <--(500 Ohm resistor, red bit 2)-- IDC 5 / GPIO37 R2
- 1 R <--(1K Ohm resistor, red bit 1)-- IDC 4 / GPIO36 R1
- 1 R <--(2K Ohm resistor, red bit 0)-- IDC 3 / GPIO35 R0
- 2 G <--(500 Ohm resistor, green bit 2)-- IDC 8 / GPIO40 G2
- 2 G <--(1K Ohm resistor, green bit 1)-- IDC 7 / GPIO39 G1
- 2 G <--(2K Ohm resistor, green bit 0)-- IDC 6 / GPIO38 G0
- 3 B <--(500 Ohm resistor, blue bit 2)-- IDC 11 / GPIO43 B2
- 3 B <--(1K Ohm resistor, blue bit 1)-- IDC 10 / GPIO42 B1
- 3 B <--(2K Ohm resistor, blue bit 0)-- IDC 9 / GPIO41 B0
- 4 N/C
- 5 GND -- 20 GND
- 6 GND -- 20 GND
- 7 GND -- 20 GND
- 8 GND -- 20 GND
- 9 N/C
- 10 GND - 20 GND
- 11 N/C
- 12 N/C
- 13 HSYNC <--(47 Ohm resistor)- IDC 12 / GPIO44 HSYNC
- 14 VSYNC <--(47 Ohm resistor)- IDC 13 / GPIO45 VSYNC
- 15 N/C
- Connector shell -- 20 GND

## a2ext-dvi

a2ext-carrier daughterboard for DVI video over an HDMI Type A connector.

- used with a2ext-dvi firmware.
- based on [A2DVI v5.x](https://github.com/rallepalaveev/a2dvi/tree/main/v5.x).

1. Read TMDS bit stream(encoded by a2ext-dvi firmware) from a2ext-carrier IDC20 connector.
2. Write to HDMI Type A connector.

### HDMI-SWM-19 <--> a2ext-carrier 20pin IDC Connector

- 1 D2+ --(270 Ohm resistor)-- IDC 8 / GPIO40 D2_P
- 2 GND -- 20 GND
- 3 D2- --(270 Ohm resistor)-- IDC 9 / GPIO41 D2_N
- 4 D1+ --(270 Ohm resistor)-- IDC 6 / GPIO38 D1_P
- 5 GND -- 20 GND
- 6 D1- --(270 Ohm resistor)-- IDC 7 / GPIO39 D1_N
- 7 D0+ --(270 Ohm resistor)-- IDC 4 / GPIO36 D0_P
- 8 GND -- 20 GND
- 9 D0- --(270 Ohm resistor)-- IDC 5 / GPIO37 D0_N
- 10 CLK+ -- (270 Ohm resistor)-- IDC 10 / GPIO42 CLK_P
- 11 GND -- 20 GND
- 12 CLK- --(270 Ohm resistor)-- IDC 11 / GPIO43 CLK_N
- 13 N/C
- 14 N/C
- 15 N/C
- 16 N/C
- 17 GND -- 20 GND
- 18 +5V_DB (slot 5V through F1/F2, before D1) -- IDC 19
- 19 N/C
- Connector shell -- 20 GND

## a2ext-lib

common library for a2ext-carrier daughter boards firmwares

- based on [a2pico](https://github.com/oliverschmidt/a2pico).
- but full address range(A0..A15) is snooped,
- and 48 GPIOs of RP2350B can be used instead of complex multiplexing for insufficient GPIO of RP2040/RP2350.

### files

- a2ext.c
- a2ext.h
- a2ext.pio : PIO program for snooping Apple II bus signals.
- and convenient stuff from a2pico to build RP2350B firmwares.

### functions(apis)

- void a2ext_init()
- uint16_t a2ext_getaddr() : read A0..A15(GPIO2..17)
- uint8_t a2ext_getdata() : read D0..D7(GPIO18..25)
- void a2ext_putdata(uint8_t data) : write D0..D7(GPIO18..25)
- void a2ext_irq(bool on) : on/off /IRQ(GPIO32)
- void a2ext_nmi(bool on) : on/off /NMI(GPIO33)
- void a2ext_on_reset(void(*reset_handler)(bool on)) : register reset_handler for /RES (GPIO31)
- void a2ext_on_sync(void(*sync_handler)(void), uint32_t counter) : register sync_handler for SYNC(GPIO34)
- void a2ext_send(uint8_t data) : transmit one byte on TX (GPIO 0; IDC20 pin 1)
- void a2ext_on_receive(void(*receive_handler)(uint32_t data)) : register receive_handler for RX(GPIO 1; IDC20 pin2)

## a2ext-vga firmware

firmware for a2ext-carrier with a2ext-vga daughter board

- based on [AppleII-VGA](https://github.com/markadev/AppleII-VGA),
- modified for a2ext-carrier.
- physical snooping of Apple II bus signals is done by a2ext-carrier with a2ext-lib.

1. Read shadowed video framebuffer and I/O space(Apple II soft-switches)
2. Update VGA framebuffer
3. Write pixels, HSYNC, VSYNC into IDC20 connector.

## a2ext-dvi firmware

firmware for a2ext-carrier with a2ext-dvi daughter board

- based on [A2DVI-Firmware](https://github.com/ThorstenBr/A2DVI-Firmware),
- modified for a2ext-carrier.
- physical snooping of Apple II bus signals is done by a2ext-carrier with a2ext-lib.

1. Read shadowed video framebuffer and I/O space(Apple II soft-switches)
2. Render the DVI output scanlines and encode TMDS data
3. Write TMDS signals to IDC20 connector.

## a2ext-demo firmware

firmware for a2ext-carrier without daughter board

- based on [a2pico demo](https://github.com/oliverschmidt/a2pico/tree/main/demo),
- modified for a2ext-carrier.
- physical snooping of Apple II bus signals is done by a2ext-carrier with a2ext-lib.

## References

- [WeAct Studio RP2350B Core Board](ref/WeActStudio.RP2350BCoreBoard/README.md)
- [Module schematic](ref/WeActStudio.RP2350BCoreBoard/HDK/RP2350B_SCH.pdf)
- [Module dimensions](ref/WeActStudio.RP2350BCoreBoard/HDK/尺寸图.pdf)

- [AppleII-VGA](https://github.com/markadev/AppleII-VGA) original by markadev
- [AppleII-VGA-rallepalaveev](https://github.com/rallepalaveev/AppleII-VGA) for RP2350B by rallepalaveev
- [A2DVI](https://github.com/rallepalaveev/a2dvi)
- [A2DVI-Firmware](https://github.com/ThorstenBr/A2DVI-Firmware)
- [A2C_DVI_Prototype](https://github.com/FarLeftLane/A2C_DVI_Prototype)
- [a2pico](https://github.com/oliverschmidt/a2pico)
- [Raspberry Pi Pico C SDK](https://www.raspberrypi.com/documentation/pico-sdk/)

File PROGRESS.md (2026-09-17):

# a2ext progress

Follow [PLAN.md](PLAN.md). Update this file and commit after every numbered step.
Only mark a step complete when its stated checks pass. Separate documentary,
automated, and physical validation.

## Status

- Steps 1-5 complete (documentary/automated checks).
- Step 6 resource allocation and passive/video assembly checks complete;
  active-response implementation/timing proof deferred to step 14.
- Step 7 schematic revised to slot-powered direct bus with signal labels
  (revision 0.5, A4 landscape); step 8 procedure updated, physical
  acceptance blocked on hardware and a measurement fixture.
- Steps 9-10 daughterboard schematics complete (revision 0.2, A4 landscape;
  automated checks).
- Steps 11-13 build setup, passive capture, and API definition complete (software checks).
- Step 14 implemented and software-checked; physical active-response timing open.
- Step 15 shared shadow model complete (host traces).
- Step 16 VGA port builds and replay passes; physical display acceptance pending.
- Step 17 DVI port builds and replay passes; physical display acceptance pending.
- Step 18 clocks, priorities and RAM budgets checked; runtime timing open.
- Step 19 automated software/ERC checks pass; physical coverage remains open.
- Steps 20-21 validation procedures, build/flashing docs and attribution complete.
- Initial software/design deliverables are committed; the direct-bus revision
  is recorded below. Physical acceptance is still open.
- Hardware acceptance: not tested; no assembled hardware available in this session.

## Work log

### All schematics — larger type and A4 landscape — 2026-09-18

- Reflowed carrier, VGA, and DVI onto one A4 landscape sheet each. Increased
  pin names/net labels/values from 1.0 to 1.524 mm, pin numbers to 1.27 mm,
  references and notes to 1.778 mm, and headings to 2.032 mm.
- Moved carrier IDC20 below the module, grouped its power components, and
  compacted the daughterboard resistor grids. Labels face outward on all
  sheets; notes fit clear of the drawing borders and title blocks.
- Regenerated schematics, local libraries, and PDFs (carrier 0.5, VGA/DVI 0.2).
  Compared every named net's endpoints with the pre-layout snapshot: all
  58/17/18 nets and electrical connections are unchanged.
- Validation: all three ERC/connectivity checks pass with zero violations;
  PDF page dimensions confirm A4 landscape (841.896 x 595.296 points), and
  rendered pages were visually reviewed. `git diff --check` passes. No firmware
  changes or physical tests were required for this presentation update.

### Carrier revision 0.4 — readable wire labels — 2026-09-17

- Replaced GP-only carrier nets with Apple II signal names, UART_TX/UART_RX,
  and IDCnn_GPIOxx daughterboard labels. Retained `_N` for active-low signals
  and documented UART direction. M1 preserves physical GPIO/header numbering;
  power pins clarify 5V/VSYS and USB VBUS. J2 now shows contact functions.
- Placed carrier net labels outward from symbols to avoid pin-number overlap,
  and regenerated the schematic, local symbols, PDF, and connectivity contract.
- Validation: compared net endpoint sets against revision 0.3; all 58 net
  connections are unchanged. Carrier ERC and connectivity checks pass with
  zero violations. Visually reviewed the PDF; no firmware change or new
  physical measurements.

### Carrier revision 0.3 — slot-only power — 2026-09-17

- User specified slot power into VSYS and no USB power, retaining D1 as
  protection. Verified the WeAct reference: H1.2 is marked 5V and feeds its
  regulator input (the VSYS function); H1.1 is USB VBUS.
- Existing slot input was already on H1.2. Renamed that rail VSYS, removed
  carrier D2, and left H1.1 NC. Retained F1/D1 and on-module U2 removal so
  USB cannot supply the module. F2 still feeds the daughterboard before D1.
- Regenerated schematic/PDF/BOM/net contract and updated power/flashing docs:
  off-host flashing uses a 5 V fixture at slot pins 25/26 plus USB data.
- Added independent netlist checks for slot/F1/D1/VSYS routing, D1 polarity,
  disconnected VBUS, and absence of D2. Physical power and USB enumeration
  tests remain NOT_RUN; firmware and GPIO assignments are unchanged.
- Validation: carrier ERC has zero violations, all 58 named-net checks and
  the GPIO pin-contract check pass, and `git diff --check` passes. Reviewed
  the exported schematic PDF against the vendor power/header drawing.

### Carrier revision 0.2 — direct bus — 2026-09-17

- User requested removal of the CB3T switches and their supporting circuit,
  superseding the isolation design recorded in steps 7-8 below.
- Removed carrier U1-U7, Q1, R1-R3, C1-C7, and BUS_GOOD/BUS_OE_N. All 33
  host signals now connect directly to GPIO2-34, retaining the optional SYNC
  jumper. R4, the existing power paths, and firmware pin assignments remain.
- Regenerated schematic, PDF, BOM, local symbols, and net contract. Compacted
  the carrier from A2 to A3 and updated independent slot/module connectivity
  checks, project documentation, and TODO.md.
- Updated operating assumptions to installed slot power and USB flashing/power
  only with the card removed from the host. Replaced switch-specific power
  tests with direct-bus supply-transition checks; physical results stay NOT_RUN.
- Validation: `python3 tools/smoke.py --erc` passes, including host regressions,
  both renderer replays/models, all three ERCs (zero violations), and direct
  connectivity checks (carrier 59 named nets). `git diff --check` passes.
  Firmware code/pin mapping did not change; the clean build matrix passed in
  the preceding status review. No new flashing or physical measurements.

### Planning baseline — 2026-09-17

- Saved the agreed 21-step implementation plan, including the per-step progress
  update and commit rule.
- Confirmed the WeAct reference module is present and KiCad CLI/CMake are
  installed. ARM GCC and Ninja are not on PATH; investigate before step 11.
- The user's staged `.gitmodules` and WeAct submodule addition predate this work;
  preserve those changes and exclude them from task commits unless requested.
- Validation: inspected repository status and local module reference paths.
- Blockers: none for starting documentation; hardware power sequencing and
  physical qualification remain explicit later gates.

### Step 1 — module and connector contract

- Updated PRD to target WeAct RP2350B Core Board V1.0, two 2x15 headers,
  60 contacts, and the module's 41.4 x 41.1 mm outline.
- Recorded II/II+/IIe compatibility and schematic-only hardware deliverables.
- Validation: compared the supplied schematic, pinout image, and dimension PDF;
  confirmed both headers number 1-30. No hardware measurements performed.
- Blockers: none for this step; physical module revision must match the reference.

### Step 2 — PRD corrections and complete deliverable list

- Corrected IDC RX, TMDS spelling, the data return type, UART description, and
  DVI rendering description. Numbered all seven outputs and included the demo.
- Validation: inspected the PRD diff; `git diff --check` passes.
- Blockers: none.

### Step 3 — WeAct module preparation

- Added powered-off preparation and continuity checks for R16 (KEY/D5), R19
  (LED/D7), and the optional secondary-memory branch on GPIO0.
- Also require R14 removal when fitted, avoiding the unused FLASH2_SS branch
  and its optional pull-up on UART TX. Keep U7/R13/C23 unpopulated.
- Validation: visually inspected the rendered vendor schematic, not only text
  extraction; R16/R19/R14 connections match the documented preparation.
- Physical module revision and resistor removal are not verified in this
  session; these are assembly prerequisites, not claimed physical work.

### Step 4 — GPIO contract

- Filled all Apple II GPIO assignments and added PHI0 to the required signals.
- Added `hw/pinout.json` as the pin-allocation source and a generated firmware
  header. `tools/pinout.py` checks uniqueness, slot/address/data ordering,
  PIO range, open-drain interrupt declarations, and exclusion of ADC pads
  from the 5 V bus.
- Validation: generator and subsequent read-only check pass; 33 bus + 2 UART +
  13 daughterboard GPIOs cover GPIO0-47 exactly; `git diff --check` passes.
- Blockers: electrical qualification remains pending; this is a logical map.

### Step 5 — daughterboard connector contract

- Assigned all IDC20 contacts, both video mappings, a second ground, 3.3 V,
  protected 5 V, and RUN. Distinguished module reset from Apple II reset.
- Extended the source pin map and generated header with VGA/DVI pins. Validate
  all 20 IDC contacts and adjacent TMDS pairs; the clock uses an even/odd pair
  to share a PWM slice with the reference serializer.
- Validation: regeneration, pin-contract check, and whitespace check pass.
- Blockers: protected power implementation and physical interface validation
  remain for hardware steps; no daughterboard has been tested.

### Step 6 — PIO, DMA, timing, and memory budgets

- Assigned separate PIO blocks and DMA IRQs; documented 126 MHz passive/VGA
  and experimental 252 MHz DVI clocking, buffer/memory budgets, and high-GPIO
  SDK requirements. Added the passive-capture PIO source.
- Validation: built pioasm from Pico SDK 2.2.0 in /tmp; assembled the capture
  program (3 words), bundled VGA programs (9+8+11 = 28 words), and bundled
  non-debug DVI serializer (2 words). Each fits its assigned PIO instruction
  store. Up to 8/16 DMA channels are reserved for capture plus DVI.
- Active response has a separate 32-word reservation but no assembled design
  or timing proof yet. Physical capture timing is also unverified. These
  limitations are explicit in `docs/resources.md`, not marked as test passes.
- User approved power-off bus isolation where required; updated PLAN/PRD.
- Blockers: none for daughterboard schematics; carrier isolation circuit still
  needs detailed electrical review in steps 7-8.

### Step 7 — carrier schematic draft

- Created a self-contained KiCad carrier project, local symbols, BOM, PDF,
  net contract, generator, and assembly/power documentation.
- Added five CB3T3245 bidirectional isolation/translation switches, dual rail
  supervisors, default-off OE control, separate RUN and Apple reset, optional
  slot-7 SYNC jumper, and explicit fused slot/USB power paths.
- Extended module preparation to remove the unidentified on-module U2 power
  path; carrier D2 restores USB power with a known diode connection.
- Validation: KiCad 10 ERC has zero violations; exported netlist verifies all
  48 module GPIO contacts, 33 switched bus paths, IDC pins, and chain links.
  Visually inspected the schematic PDF. No physical measurements performed.
- Blockers: module regulator rating, brownout timing, and host signal loading
  remain unqualified; this is a schematic prototype, not a fabrication release.

### Step 8 — power-sequencing gate

- Documented the isolation ratings, supervisor thresholds, undefined ramp
  regions, module-part uncertainties, and an explicit power-source/brownout
  measurement matrix in `hw/a2ext-carrier/POWER-VALIDATION.md`.
- Removed KiCad's per-user `.kicad_prl` state from tracking and added generated
  build/cache ignores.
- Validation: manufacturer datasheet review and the earlier ERC/net checks;
  no physical qualification is claimed.
- Blocker: no assembled carrier, identified module regulator, or scope fixture
  is available. Keep this gate open while independent steps continue.

### Step 9 — VGA daughterboard

- Added the VGA KiCad project, local symbols, BOM, PDF, and connectivity
  contract with 9 DAC resistors and two sync resistors.
- Documented nominal 75-ohm DAC levels (0-0.6861 V), per-pin loading, grounding,
  and the direct-mating baseline.
- Validation: zero ERC violations and exported netlist checks; ideal DAC
  calculation checked. Physical signal levels/timing remain untested.
- Blockers: physical acceptance requires a built board, scope, and monitor.

### Step 10 — DVI daughterboard

- Added the HDMI Type A schematic, project-local symbols, BOM, PDF, and
  connectivity contract; all four TMDS pairs use 270-ohm series resistors.
- Documented pair polarity, clock PWM pairing, GPIO-base/mask changes required
  by libdvi, fused pin-18 supply, unused interfaces, and direct mating.
- Validation: zero ERC violations and exported netlist checks; compared
  positive/negative mapping with the reference serializer instructions.
- Blockers: no physical TMDS/monitor tests; abstract connector shell pin must
  be mapped to the chosen part if PCB layout is later undertaken.

### Step 11 — reproducible firmware build setup

- Added CMake targets for demo/VGA/DVI, shared-library build rules, prepared
  WeAct board definition, dependency revisions, and build instructions.
- Initial targets only initialize bus pins as inputs; they do not yet capture,
  respond to slot reads, or generate video. Default LED/button pins are absent.
- Validation: built all three ELF/UF2/map sets using Pico SDK/picotool 2.2.0 and
  ARM GCC 14.2.1/newlib. Compiler packages were extracted under /tmp without
  changing system packages; build artifacts stay in ignored `build/`.
- The SDK warns that TinyUSB is absent; USB stdio is explicitly disabled and
  all targets built successfully. No physical flashing was performed.
- Blockers: none for software implementation; the hardware gate remains open.

### Step 12 — passive DMA bus capture

- Added chained DMA capture into two 1024-word blocks, atomic cycle decoding,
  FIFO-stall/overwrite detection, stream epochs, and resynchronization. Demo
  now consumes the passive capture stream; video targets remain bring-up code.
- Capturing, polling, stopping, and statistics access belong to the same core;
  its DMA IRQ1 owns completion handling. No UART/render callback runs there.
- Validation: all three targets rebuild successfully. Host tests cover every
  16-bit address, data/select decoding, ordered block consumption, repeated
  wrap, and rejection when DMA would overwrite an unread or partial block.
- On resume, /tmp dependencies were gone. Reused the matching SDK at
  `/home/iolo/pico-sdk`, restored ARM packages under ignored `.cache/`, and
  created `build/resumed`. The SDK now has TinyUSB, still disabled for stdio.
- Blockers: physical PIO sampling, DMA throughput, and electrical qualification
  remain untested; host queue tests do not emulate the RP2350 DMA engine.

### Step 13 — common library API

- Added latched address/data getters, open-drain IRQ/NMI helpers, UART0 byte
  transport, and deferred reset/receive/composite-SYNC callbacks. Reset releases
  interrupt outputs; callback queue overflow is observable.
- Documented core ownership, callback dispatch limits, SYNC counting, capture
  epochs, and read-data limitations. `try_putdata` still rejects all output
  until the bounded active response path is implemented in step 14.
- Validation: all three targets compile/link with warnings treated as errors;
  capture decoding/queue regression tests still pass. GPIO/UART behavior has
  not been tested on hardware.
- Blockers: active response implementation and physical timing proof remain.

### Step 14 — experimental slot responder and a2pico demo

- Added an opt-in 27-word PIO responder with per-cycle tags, C800 ownership,
  CFFF release, delayed write sampling, and fail-closed FIFO/mismatch faults.
  Ported the MIT a2pico 6502 ROM and UART/register/IRQ/NMI demo. Default remains
  passive; active builds explicitly use experimental 252 MHz and SRAM code.
- Validation: active and passive firmware builds, host slot-policy regression,
  and an instruction-level PIO test pass. The latter sweeps reply enqueue
  phases, rejects stale/zero tags, checks wrap, and checks bounded release;
  it does not model synchronizers, CPU latency, or electrical timing.
- Limitations: no physical response deadline proof. Final enable can race a
  falling edge (up to four PIO cycles to release, plus synchronization), reset
  does not cancel an already queued PIO reply, and callback side effects are
  not acknowledged by successful CPU sampling. Active mode is experimental.

### Step 15 — shared video shadow

- Added 64 KiB main/aux banks with byte validity, II/II+ versus IIe selection,
  video switches, ALTZP/AUXWRITE/80STORE precedence, and capture-epoch loss
  invalidation. Read cycles never populate RAM from unqualified read data.
- Extended passive samples to include /RES in the same 32-bit DMA word, so
  reset handling follows captured bus order rather than delayed callbacks.
  Warm reset retains RAM/validity and conservatively reacquires switches;
  writes with unknown bank selection are ignored until selection is known.
- Cross-core readers use atomic bytes and validity; frame copies may tear but
  avoid undefined concurrent accesses. I/O, ROM, language-card and expansion
  banking are explicitly outside the RAM shadow contract.
- Validation: host traces pass for bank precedence, 40/80-column and graphics
  switches, reset retention, unknown initial contents, and capture loss.
  Three firmware targets rebuild; capture and slot regressions pass.

### Step 16 — VGA renderer and output port

- Ported the bundled AppleII-VGA text/lores/hires/double-mode renderer, fonts,
  scanline DMA and 28-word PIO programs with MIT attribution. Shared capture
  begins on core 1 before renderer initialization; frame copies isolate the
  renderer from concurrent shadow writes. Added IIe/II+ and test-pattern builds.
- Corrected PIO1 GPIO base, nine-pin OUT setup and RGB bit order, including
  precomputed artifact-color tables. Output remains 640x480 with centered
  560x384 content; model-specific font selection is explicit.
- Validation: all firmware targets compile/link with -Werror. Host renderer
  replay is scheduled in step 19; physical sync/color/throughput checks remain
  open. Added 48 KiB frame-copy storage beyond the original memory estimate;
  final linker-size accounting is step 18 work.

### Step 17 — A2DVI renderer and serializer port

- Retained A2DVI's text/lores/hires/double-mode renderers, TMDS palettes and
  libdvi PIO/DMA serializer with licenses. Adapted high-pin masks, PIO1 base 16,
  RAM sections, pair polarity, model/font selection and shared frame copies.
- Removed upstream debug/status-row demand from the scanline consumer; it now
  displays 384 content lines centered in 480. Eight TMDS buffers use 30 KiB.
  No original transceiver capture, menus, LED/button GPIOs or custom flash
  configuration code runs in this target.
- Validation: all three firmware targets compile/link with -Werror. Renderer
  replay is step 19 work; hardware DVI/capture throughput is not measured.
  The required 252 MHz remains explicitly experimental with no voltage change.

### Step 18 — clock, priority and memory integration

- Fixed both outputs at nominal 640x480/60 Hz (25.2 MHz pixels, 800x525 total).
  Capture remains 126 MHz across VGA/DVI system clocks, with a dedicated core,
  high-priority DMA/IRQ and SRAM hot paths. UART diagnostics are bounded and
  nonblocking; DVI exposes missed-scanline count.
- Added ELF SRAM accounting including frame copies and a separate DVI runtime
  buffer/queue allowance. Current VGA total is 232,332 bytes; DVI conservative
  total is 288,060 bytes, within 520 KiB. No full RGB framebuffer is allocated.
- Validation: all three Release builds pass, clock/divider arithmetic reviewed,
  memory report passes. PLL/timing/overclock stability and simultaneous live
  capture/render throughput remain physical acceptance tests, not build claims.

### Step 19 — automated checks and renderer replay

- Added one-command host/pin/ERC verification and clean firmware matrices for
  IIe, II/II+ with active demo, and video patterns. All nine ELF/UF2/map sets
  build, and SRAM budgets pass. All three schematics retain zero ERC violations.
- Replayed real VGA/DVI renderer sources into host pixel sinks with bounds/UB
  sanitizers. Checked dimensions, page/80STORE selection, mixed text rows,
  double modes and matching normal/inverse/flashing/alternate text in both
  host models. Saved reproducible PPM artifacts under ignored build/replay.
- Fixed DVI double-hires signed shifts, II/II+ character-ROM flash handling and
  flash-phase agreement. Added IOUDIS gating after inspecting the Apple IIe
  Technical Reference Manual table 2-10. Retained conservative reset recovery.
- Concurrent desktop test passes 1,572,864 decoded writes with frame snapshots,
  reset and capture-loss invalidation. It does not benchmark target DMA.
- Detailed coverage/limitations are in docs/VERIFICATION.md. Physical missing
  SYNC, UART/interrupt behavior, response timing and live video/capture load
  tests cannot run without hardware; those acceptance items remain open.

### Step 20 — physical validation procedure

- Published fixture-first assembly/power, passive capture/loading, active timing,
  IRQ/NMI/reset/UART/SYNC, video levels/monitor stability and simultaneous-load
  procedures with measurable acceptance conditions and an evidence worksheet.
- Documented explicit IIe switch initialization/redraw for conservative shadow
  acquisition and the unresolved active-response edge/reset races.
- Validation: reviewed against implemented pin/resource/API contracts and the
  existing power gate. Every physical worksheet entry remains NOT_RUN; no board,
  instrument reading, flashing, monitor result or live host test is claimed.

### Step 21 — documentation and handoff

- Replaced the placeholder README with deliverable links, build/check workflow,
  compatibility matrix, module preparation, initialization behavior, attribution
  and explicit physical limits. Expanded firmware setup/options/flashing and
  recovery instructions; included the verified local toolchain configuration.
- Resolved obsolete PRD power/pull-up placeholders to match the schematics and
  updated the plan's power gate wording to the approved isolation design.
- Validation: reviewed local documentation links and repository diff; final
  source builds and software checks passed in step 19. No flashing performed.
- Remaining acceptance: step 8 power qualification, active response edge/reset
  races and setup/hold timing, target capture/render load, UART/interrupt/SYNC,
  VGA levels and DVI stability. The measurement worksheet records all as NOT_RUN.
  Completion of documentation does not close these physical gates.

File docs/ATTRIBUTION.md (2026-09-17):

# Upstream attribution

The `ref/` repositories remain unmodified by the implementation. Adapted source
is copied under `fw/` so builds do not depend on local changes in a reference
checkout. Exact upstream revisions are in `fw/dependencies.json`.

| Source | Adapted material | Preserved notices |
|---|---|---|
| Oliver Schmidt, a2pico | Demo 6502 ROM/linker layout and slot-terminal concept | MIT headers in demo source; `ref/a2pico/LICENSE` |
| Mark Aikens / David Kuder, AppleII-VGA via rallepalaveev | VGA renderers, RGB tables, fonts, PIO and scanline DMA | `fw/a2ext-vga/LICENSE` |
| Mark Aikens / David Kuder / Thorsten Brehm, A2DVI-Firmware | DVI renderers, fonts, TMDS patterns and library variant | `fw/a2ext-dvi/LICENSE` and source headers |
| Luke Wren / libdvi contributors | TMDS PIO serializer, DMA/queue and timing machinery, as bundled with A2DVI | `fw/a2ext-dvi/libdvi/LICENSE` |
| WeAct Studio | RP2350B Core Board V1.0 schematic, pinout and mechanical references | Vendor files under `ref/WeActStudio.RP2350BCoreBoard` |
| Raspberry Pi | Pico SDK/picotool build and peripheral APIs | External dependencies retain their own notices |

New integration includes the shared GPIO contract, direct-bus carrier and power
schematics, passive DMA capture, tagged experimental responses, shadow model,
frame adapters and verification tools. Port modifications are described in each
firmware README. No claim of upstream hardware endorsement or certification is
made. The original license texts travel with the adapted sources.

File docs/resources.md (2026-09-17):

# RP2350B resource and timing contract

Pin assignments originate in `hw/pinout.json`; run `python3 tools/pinout.py`
to check the generated firmware header. Use Pico SDK 2.2.0 (commit
`a1438dff1d38bd9c65dbd693f0e5db4b9ae91779`) for the initial implementation.

## Resource allocation

| Function | PIO/base | State machines | Program words | DMA channels |
|---|---|---|---|---|
| Passive bus capture | PIO0 / 0 | SM0 | 3 of 32 | 2 reserved for alternating blocks |
| VGA (exclusive with DVI) | PIO1 / 16 | SM0-2 | 28 of 32 from reference | 1 |
| DVI (exclusive with VGA) | PIO1 / 16 | SM0-2 | 2 shared words at origin 0 | 6 (3 data, 3 control) |
| Active slot responder | PIO2 / 0 | SM0 | 27 of 32 | CPU FIFO service |
| Active delayed write sample | PIO0 / 0 | SM1 | 3 additional words | CPU FIFO service |

The passive and video programs can coexist without shared instruction memory,
state machines, or pins. The active responder assembles to 27 words; its instruction-level regression
checks cycle tags and release logic, but physical response timing is unproven.
The RP2350 has 16 DMA channels; reserve at most 8 for capture plus DVI. Claim
channels through the SDK, not hard-coded channel numbers. Use DMA IRQ0 for
video and IRQ1 for capture; the bundled video implementations use exclusive
handlers. GPIO/UART handlers and deferred callbacks run on core 0; core 1 owns
bus consumption and optional active responses. Renderer work runs on core 0.

Initialize each PIO's GPIO base before adding programs. GPIO35-45 video outputs
are in PIO1's GPIO16-47 window. Use the SDK's 64-bit mask APIs and `1ull << pin`
for high GPIOs; the reference DVI helpers' `3u << data_pins` are not valid for
these assignments. SDK pin configuration functions accept physical GPIO numbers;
PIO instruction immediate GPIO operands must respect the PIO base.

DVI clock GPIO42/43 is an even/odd pair on one PWM slice; reserve that slice
for the pixel clock. PIO produces the three TMDS data pairs. HSTX is not used:
its fixed GPIO range conflicts with the bus assignment. UART0 uses GPIO0/1;
never configure the module's default LED/button GPIOs.

## Capture timing and capacity

`a2ext_capture` waits for PHI0 low then high and samples GPIO2-31 after the
29-cycle delay. At a 126 MHz SM clock, the sample is approximately 32 SM clocks
(254 ns) after the observed external edge, allowing for input synchronization.
This follows the direct-capture reference's write-data sampling window; scope
measurements must account for direct wiring, bus loading, and host model.
Do not disable input synchronizers until measured timing justifies it.

The 30-bit word is shifted left and autopushed: bits 0-15 address, 16-23 data,
24 RWB, 25 /DEVSEL, 26 /IOSEL, 27 /IOSTRB. Bit 28 is PHI0 and bit 29 is /RES, preserving reset order with the stream.
Select bits are active low. Capture
every PHI0 CPU cycle, not only slot-selected traffic. Read-cycle data is not
guaranteed valid at this sample instant; writes and read-side soft-switch
addresses are sufficient for the initial shadow model.

At a design budget of 1.1 million cycles/s, DMA traffic is 4.4 MB/s. Reserve
two 1024-word blocks (8 KiB), allowing about 0.93 ms per block. Joined RX FIFO
holds 8 words, only about 7.3 us at that rate: block DMA must chain without a
CPU rearm gap. FIFO stalls and unconsumed block reuse must both invalidate
shadow state; neither is recoverable by silently continuing the old stream.

Use a 126 MHz capture SM clock: divider 1 for 126 MHz demo/VGA and divider 2
for a 252 MHz DVI system clock. DVI's 252 MHz clock is above the RP2350's
150 MHz rating and remains an explicit experimental configuration requiring
physical qualification; do not raise the core voltage without a separate
documented rating review. If the clock cannot be established, remain passive
and report failure rather than changing timing silently.

## Memory envelope and remaining timing gate

Reserve 128 KiB for main/auxiliary shadow memory, 16 KiB for byte-validity maps,
8 KiB for capture blocks, and at most 32 KiB for video scanline/TMDS buffers.
Keep code, stacks, queues, and other data within the remaining SRAM verified
by linker maps; do not allocate a full 640x480 RGB framebuffer. Firmware
builds must report actual RAM usage rather than treating this budget as proof.

The delayed passive capture cannot serve slot reads on its own. PIO2 needs an
earlier request path, an explicit deadline, and a cycle identity so late CPU
responses cannot drive the following cycle. Gate outputs with read/selection,
PHI0, reset, and C800 ownership. There is no physical response-timing claim
until step 14's implementation and the hardware procedure pass.

Sources: bundled `ref/AppleII-VGA-rallepalaveev/pico/vga.pio`,
`ref/A2DVI-Firmware/libraries/libdvi/dvi_serialiser.pio` and `dvi.c`, and the
[RP2350 datasheet](https://datasheets.raspberrypi.com/rp2350/rp2350-datasheet.pdf).

## Implemented clocks and scheduling

Both backends use a 25.2 MHz pixel clock, 800 pixels/line and 525 lines/frame:
31.5 kHz horizontal and exactly 60 Hz nominal vertical. VGA system/capture
clock is 126 MHz; RGB PIO runs at 50.4 MHz and sync PIO at 3.15 MHz. DVI system
and serializer run at 252 MHz, PWM divides by 10, and capture SM divides by 2.
All clock changes happen before UART/capture initialization. No voltage override
is used. DVI and the opt-in active demo exceed the rated 150 MHz; their actual
operating margin is unmeasured. PLL lock/build success is not qualification.

Capture DMA uses high-priority channels and IRQ1 at highest priority on core 1.
Video DMA/IRQ0 and UART/event dispatch stay on core 0. Capture polling, statistics
and shadow-write hot paths reside in SRAM. Frame copies add 48 KiB to the initial
memory budget; renderers operate on these copies without blocking capture.
UART status output sends at most 16 immediately writable bytes per frame, so a
slow UART cannot stall the renderer. The DVI status includes missed scanlines.
No video output is synchronized to optional slot-7 SYNC.

`tools/memory_report.py BUILD --size-tool /path/to/arm-none-eabi-size` checks
allocated SRAM sections and a separate DVI runtime-allocation allowance.
Release build at step 18 (bytes, including minimum heap and both stacks):

| Target | Allocated SRAM | Additional runtime allowance | Remaining of 520 KiB |
|---|---:|---:|---:|
| Passive demo | 17,688 | 0 | 514,792 |
| VGA | 232,332 | 0 | 300,148 |
| DVI | 256,316 | 31,744 | 244,420 |

The DVI allowance covers 30,720 bytes of TMDS data plus 1 KiB for queues and
allocation overhead; minimum heap already counted above makes this conservative.
Map sizes vary with toolchain/configuration. Stack high-water marks, worst-case
capture service time and live DMA/render throughput still require measurement.

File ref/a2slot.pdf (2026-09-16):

# Apple II Slot

## 50-pin double-sided edge connector expansion slot used in Apple II, II+, IIe, and IIGS computers, carrying the

6502 address, data, and clock buses.

1 2 3 4 5 6 7 8 9 10 11 12 13 14 15 16 17 18 19 20 21 22 23 24 25

50 49 48 47 46 45 44 43 42 41 40 39 38 37 36 35 34 33 32 31 30 29 28 27 26

Apple II - 50 pin female bus

connector

The Apple II peripheral expansion slot is a proprietary 50-pin double-sided edge connector (25 contacts per side, 100 mil pitch, 200 mil row spacing) introduced with the Apple II in 1977 and retained, with minor signal changes, through the Apple IIe and Apple IIGS. It exposes the 6502-family bus directly: a 16-bit address bus (A0–A15), an 8-bit bidirectional data bus (D0–D7), phase clocks, interrupt and DMA daisy-chain lines, and four power rails (+5 V, −5 V, +12 V, −12 V). Up to seven slots are provided in the IIe (Slots 1–7); the IIGS retains the same seven slots with full backward compatibility. Several pin assignments dier between models — most notably pins 19, 35, and 39 — so card designers must account for the target platform.

Pin | Name | Direction | Description
1 | /IOSEL | OUT | I/O Select. Active when page $Cn gets accessed. N.C. on slot 0
2 | A0 | IN/OUT | Buered address bus
3 | A1 | IN/OUT | Buered address bus
4 | A2 | IN/OUT | Buered address bus
5 | A3 | IN/OUT | Buered address bus
6 | A4 | IN/OUT | Buered address bus
7 | A5 | IN/OUT | Buered address bus
8 | A6 | IN/OUT | Buered address bus
9 | A7 | IN/OUT | Buered address bus
Apple II Slot · AllPinouts | https://allpinouts.org/pinouts/connectors/buses/apple-ii-slot/
1 of 5 | 9/16/26, 10:00

Pin | Name | Direction | Description
10 | A8 | IN/OUT | Buered address bus
11 | A9 | IN/OUT | Buered address bus
12 | A10 | IN/OUT | Buered address bus
13 | A11 | IN/OUT | Buered address bus
14 | A12 | IN/OUT | Buered address bus
15 | A13 | IN/OUT | Buered address bus
16 | A14 | IN/OUT | Buered address bus
17 | A15 | IN/OUT | Buered address bus
18 | R/W | IN/OUT | Buered Read/Write signal.
19 | SYNC | OUT | Only Slot 7. SYNC from Video Generator. Not on Rev 0 Boards. Testpin on Slot 1 for //e
20 | /IOSTRB | OUT | I/O Strobe. Active when $C800 and $CFFF gets accessed
21 | /RDY | IN | Activation during Phi1 will halt the CPU, with the address bus holding the last address
22 | /DMA | IN | Activation disables the 6502"s address bus and halts the CPU
23 | /INTOUT | IN | Daisy-chained interrupt output to lower priority devices
24 | /DMAOUT | IN | Daisy-chained DMA output to lower priority devices
25 | +5V | | +5 Volt power supply. Max. 500mA for ALL peripheral boards
26 | GND | | System electrical ground
27 | /DMAIN | OUT | Daisy-chained DMA input from higher priority devices
28 | /INTIN | OUT | Daisy-chained interrupt input from higher priority devices
29 | /NMI | IN | Non-Maskable Interrupt. Monitor ROM starts interrupt handling routine at location $3FB
30 | /IRQ | IN | Interrupt ReQuest. Monitor starts the routine pointed to by $3FE/F

Pin | Name | Direction | Description
31 | /RES | IN | RESet
32 | /INH | IN | INHibits the on board ROMs ($D000-$FFFF)
33 | -12V | | -12 Volt power supply. Max. 200mA for ALL peripheral boards
34 | -5V | | -5 Volt power supply. Max. 200mA for ALL peripheral boards
35 | COLORREF | OUT | Only Slot 7. 3.5 MHz Video COLOR REF. Not on Rev 0 Boards. Testpin on Slot 1 for //e. M2B0 on A2gs
36 | 7M | OUT | 7Mhz clock
37 | Q3 | OUT | 2Mhz asymetrical clock
38 | PHI1 | OUT | 1 MHz phase 1 clock
39 | Various | OUT | USER1 on A2: Disable adressdecode. 65C02 SYNC on A2e. M2SEL on A2gs
40 | PHI0 | OUT | 1 MHz phase 0 clock (Inverted PHI1)
41 | /DEVSEL | OUT | DEVice SELect. Active when $C0nX gets accessed; n -Slot#+8
42 | D7 | IN/OUT | Buered bi-directional data bus
43 | D6 | IN/OUT | Buered bi-directional data bus
44 | D5 | IN/OUT | Buered bi-directional data bus
45 | D4 | IN/OUT | Buered bi-directional data bus
46 | D3 | IN/OUT | Buered bi-directional data bus
47 | D2 | IN/OUT | Buered bi-directional data bus
48 | D1 | IN/OUT | Buered bi-directional data bus
49 | D0 | IN/OUT | Buered bi-directional data bus
50 | +12V | | +12 Volt power supply. Max. 250mA for ALL peripheral boards

Notes

- Signal names prexed with / (or shown with a leading slash in the table) are
active-low.
- The slot is a 25-nger double-sided edge connector; the component side carries odd-numbered pins and the solder side carries even-numbered pins by convention.
- Power budgets are cumulative across all installed cards: +5 V is limited to 500 mA total, −5 V and −12 V to 200 mA each, and +12 V to 250 mA total for all peripheral boards.
- Slot-specic signals (pins 19, 35, 39) vary by model and by slot number:
- Pin 19 carries SYNC (horizontal/vertical video sync) only on Slot 7 of the original Apple II; on the IIe it becomes a test point on Slot 1.
- Pin 35 carries the 3.58 MHz colour-reference signal (COLORREF) on Slot 7 of the Apple II/IIe; on the IIGS it is reassigned to M2B0.
- Pin 39 is USER1 (address-decode disable) on the Apple II, 65C02 SYNC on the IIe, and M2SEL on the IIGS.
- The /INH signal inhibits the on-board ROMs in the $D000–$FFFF range, allowing peripheral cards to substitute their own ROM.
- DMA and interrupt priority are resolved by daisy-chaining: /DMAIN/DMAOUT and / INTIN/INTOUT pass priority from higher-numbered to lower-numbered slots.
- The Apple IIGS retains the same 50-pin edge connector and maintains backward compatibility with Apple IIe peripheral cards.

Signals

- /IOSEL — I/O Select; asserted when page $Cn is accessed (where n = slot number); not connected on Slot 0.
- A0–A15 — Buered 16-bit address bus from the 6502-family CPU.
- R/W — Buered Read/Write signal; high = read, low = write.
- SYNC — (Slot 7 only, Apple II/II+) SYNC output from the video generator; used as a test point on Slot 1 of the IIe; absent on Revision 0 boards.
- /IOSTRB — I/O Strobe; asserted when addresses $C800–$CFFF are accessed.
- /RDY — Ready; when asserted during PHI1, halts the CPU with the address bus frozen at the last address.
- /DMA — Direct Memory Access request; disables the 6502 address bus and halts the CPU, allowing a peripheral to take bus control.
- /INTOUT — Daisy-chained interrupt output passed to lower-priority (higher-numbered) devices.
- /DMAOUT — Daisy-chained DMA output passed to lower-priority devices.
- +5V — +5 V power rail; maximum 500 mA shared across all peripheral cards.
- GND — System ground.
- /DMAIN — Daisy-chained DMA input received from higher-priority devices.

- /INTIN — Daisy-chained interrupt input received from higher-priority devices.
- /NMI — Non-Maskable Interrupt; the Monitor ROM begins interrupt handling at $3FB.
- /IRQ — Interrupt ReQuest; the Monitor begins the routine pointed to by $3FE/ $3FF.
- /RES — Reset signal.
- /INH — Inhibit; disables on-board ROMs in the $D000–$FFFF range.
- −12V — −12 V power rail; maximum 200 mA shared across all peripheral cards.
- −5V — −5 V power rail; maximum 200 mA shared across all peripheral cards.
- COLORREF — (Slot 7 only, Apple II/IIe) 3.58 MHz colour reference; absent on Revision 0 boards; reassigned to M2B0 on the IIGS.
- 7M — 7 MHz master clock output.
- Q3 — 2 MHz asymmetrical clock output.
- PHI1 — 1 MHz phase-1 clock.
- Various (pin 39) — USER1 (address-decode disable) on the Apple II; 65C02 SYNC on the IIe; M2SEL on the IIGS.
- PHI0 — 1 MHz phase-0 clock (inverted PHI1).
- /DEVSEL — Device Select; asserted when $C0nX is accessed, where n = slot number + 8.
- D0–D7 — Buered bidirectional 8-bit data bus.
- +12V — +12 V power rail; maximum 250 mA shared across all peripheral cards.

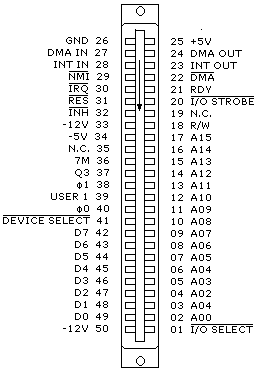
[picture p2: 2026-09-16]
ref/a2slot.png

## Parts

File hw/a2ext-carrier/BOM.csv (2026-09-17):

Reference | Value | Footprint | Assembly note
J1 | Apple II slot, counter-clockwise numbering
JP1 | SYNC: OPEN except verified slot 7
M1 | WeAct RP2350B V1.0 (prepared module) |  | Remove R16, R19, R14, U2; U7/R13/C23 unpopulated. H1.2 5V is VSYS; H1.1 VBUS is NC. USB data only.
J2 | Daughterboard IDC20
R4 | 10k
D1 | SS14
F1 | 500mA PTC
F2 | 100mA PTC
C8 | 100nF
C9 | 10uF
C10 | 10uF
#FLG01 | PWR_FLAG
#FLG02 | PWR_FLAG

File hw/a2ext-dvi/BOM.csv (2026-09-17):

Reference | Value | Footprint | Assembly note
J1 | Carrier IDC20
J2 | HDMI-SWM-19 / Type A |  | Verify chosen connector footprint; SH represents all shell contacts
R1 | 270R 1%
R2 | 270R 1%
R3 | 270R 1%
R4 | 270R 1%
R5 | 270R 1%
R6 | 270R 1%
R7 | 270R 1%
R8 | 270R 1%
C1 | 100nF

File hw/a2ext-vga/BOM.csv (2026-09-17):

Reference | Value | Footprint | Assembly note
J1 | Carrier IDC20
J2 | DE-15HD female |  | Shell contact modeled as SH; select physical connector before PCB layout
R1 | 2k 1%
R2 | 1k 1%
R3 | 500R 1%
R4 | 2k 1%
R5 | 1k 1%
R6 | 500R 1%
R7 | 2k 1%
R8 | 1k 1%
R9 | 500R 1%
R10 | 47R
R11 | 47R

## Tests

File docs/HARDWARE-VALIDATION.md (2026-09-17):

# Physical validation procedure

**Status: NOT RUN.** This repository contains schematic prototypes and firmware
that pass software checks. No assembled carrier, bus fixture or monitor was
available. Record results in `hardware-results.csv`; an empty measurement or
an ERC pass must not be treated as a physical pass.

## Equipment and record

Use a prepared WeAct V1.0 module, assembled carrier, directly mated daughterboard,
current-limited supplies, DMM, scope with low-capacitance probes, logic analyzer,
and a controlled 5 V bus fixture before connecting an Apple II. Include a 75-ohm
VGA termination and an appropriate differential probe for TMDS; do not load a
TMDS pair with a long single-ended probe ground lead. Record board/BOM revisions,
module regulator identity, RP2350 stepping, firmware commit and UF2 hash, host
model/slot, supply voltage, temperature, monitor/cable, instruments and waveform
paths. Photograph connector orientation and module modifications.

## 1. Assembly and power gate

With all power removed, verify module R16/R19/R14 and on-module U2 isolation,
secondary-memory population, slot orientation, ground continuity, chain links,
IDC pin 1, and open JP1 unless using a documented slot-7 SYNC source. Inspect
resistor values and diode polarities. Revision 0.2 has direct bus connections;
verify slot-to-module continuity, with JP1 open in the optional SYNC path.

Complete every scenario in
[POWER-VALIDATION.md](../hw/a2ext-carrier/POWER-VALIDATION.md), including slot
startup/shutdown, slow ramps, brownouts, RUN, externally powered off-host
USB/BOOTSEL operation, and UART attachment. USB is data only; bench power goes
to slot pins 25/26 with the card removed. Do not hot-plug the card.
Compare voltage traces against component ratings;
identify the regulator and qualify current/temperature. Resolve failures before
connecting a host. Establish the maximum intended slot/daughterboard load and
check fuse/diode drop at that load. Verify USB cannot power the module and
slot power does not feed back into VBUS; the fused slot rail supplies HDMI +5 V.

## 2. Passive capture and bus loading

Load the default passive demo with the host disconnected. Drive the fixture
through the qualified carrier with data outputs released. Replay sequential and
pseudorandom full addresses, walking data bits, reads/writes, selects, consecutive
cycles and reset transitions, first slowly and then at each host's actual bus
rate (include a 1.1 MHz stress point). Compare decoded cycles with the fixture
trace; use an instrumented capture dump or debugger only with the fixture halted.

Measure PHI0 and write-data setup/hold at both the slot and module pins. The PIO
sample is nominally about 254 ns after rising PHI0 at 126 MHz; include wiring and
input-synchronizer delay in the measured margin. Compare against the installed
CPU's timing limits. Observe all signal rise/fall times and logic levels with
and without the carrier. Verify input pull behavior during startup and loader
entry. Read data is not guaranteed by this sampling instant and is not used to
populate shadow RAM.

Run at least 30 minutes of worst-case writes. Require zero unexplained lost,
duplicated or corrupted cycles and zero capture overflows. Deliberately delay
consumption using an instrumented firmware build: the overflow counter/epoch
must advance, stale queued data must be discarded, and shadow validity must be
cleared. Remove the delay and verify recovery after explicit switch setup and
RAM redraw. Save the instrumented source diff with results.

## 3. Active response, only after the preceding gates

Use `A2EXT_DEMO_ACTIVE=ON` on the fixture before a host. This build runs from SRAM
at experimental 252 MHz. Probe D0-D7, RWB, PHI0, /RES, and all slot selects.
Test every data bit in selected Cnxx ROM and C0n0 register reads/writes.
Confirm no output on RAM, writes, unselected cycles, or C800 without ownership.
Acquire ownership with local Cnxx, read C800, access another slot's Cnxx, and
verify release. Repeat with CFFF release and reset.

Measure request-to-valid data, setup at the CPU sampling edge, and release time.
Sweep response delays across rising/falling PHI0 in an instrumented build,
including an old response arriving during the following selected read/write.
Require no stale-cycle output and no contention with the fixture/host. The PIO
logic permits a final-enable race of up to four internal PIO cycles after a
falling edge, plus synchronization/propagation; acceptance depends on measured
host timing, not the host interpreter test. Reset can race an already queued
reply. If those cases violate host requirements, revise the responder or add
hardware gating before accepting active operation.

Induce FIFO loss: output must release and `slot_faulted` must latch. Confirm
explicit disable releases before stopping PIO. Never pause PIO/core debugging
on a live host bus. Callbacks are not acknowledged reads: UART/register side
effects can occur when a reply misses the CPU deadline. Qualify this behavior
before using the demo as anything beyond a terminal experiment.

## 4. UART, reset, interrupts and optional SYNC

With 3.3 V UART at 115200 8N1, exercise RX/TX bursts and `?` diagnostics while
capturing. Verify overflow/drop reporting. Check IRQ/NMI with a scope: assertion
is low, release is high impedance with host pull-ups, and Apple reset releases
both. The active demo maps UART ESC to IRQ and Ctrl-N to NMI; a write to register
offset 1 releases them. Verify correct host handling with a suitable IRQ/NMI
handler installed before asserting either.

Keep JP1 open and confirm both video targets operate without SYNC. On a verified
slot-7 source only, close JP1 and instrument a registered callback; confirm it
counts composite-sync falling edges with the requested divider, not PHI0. Check
counter 0/unregister and missing-input behavior. Check reset callback ordering
and data-pin release through repeated host resets and module RUN operations.

## 5. Shadow acquisition and video modes

Capture cannot reconstruct RAM written before startup or before an overflow.
Unknown-bank writes are discarded, and RESET retains RAM but reacquires switch
state from subsequent accesses. For a repeatable IIe bench test, at a normal
main-memory Applesoft prompt explicitly initialize switches, then redraw:

```basic
POKE 49152,0:POKE 49154,0:POKE 49156,0:POKE 49160,0
POKE 49164,0:POKE 49166,0:POKE 49278,0:POKE 49247,0
POKE 49236,0:POKE 49238,0:POKE 49234,0:TEXT:HOME
```

This is a diagnostic setup that changes display/banking state; do it between
applications, not inside a program relying on auxiliary memory. For II/II+ use
the IIPLUS build and `TEXT:HOME`. After loss/reset repeat setup and redraw. UART
`known` reports acquired flags; no firmware feature automatically reads host RAM.

Compare host and reproduced output for 40-column normal/inverse/flashing text,
lores, hires, mixed text rows, both pages, IIe 80-column/alternate charset,
double-lores/double-hires, AUXWRITE/ALTZP/80STORE interactions, and IOUDIS gating.
Use deliberately different main/aux patterns. Verify reset retains observed RAM
and loss never silently presents old shadow as fully valid. Unknown bytes are
rendered as zero and may produce visible placeholder glyphs.

## 6. VGA and DVI acceptance

Start with the test-pattern firmware, then host modes. VGA: measure each DAC bit
and full white into 75 ohms (ideal full scale 0.6861 V), monotonicity, channel
order and sync levels. Nominal output: 25.2 MHz pixels, 31.5 kHz lines, 60 Hz
frames, negative sync, 800x525 totals, 96-pixel HSYNC and 2-line VSYNC. Check
content placement, blanking, pulse widths and no visible underruns.

DVI: verify connector +5 V under load, pair polarity/levels and clock, stable
640x480 lock, absence of sparkles/dropouts, and reconnect/power-order behavior.
Use multiple monitors and record each cable. The 252 MHz clock exceeds RP2350's
150 MHz rating: verify repeated cold starts and sustained operation across the
intended supply/temperature envelope. No core-voltage override is authorized by
this design. Direct mating is the baseline; qualify each ribbon configuration
separately with signal-integrity measurements.

For each video backend, repeat the 30-minute capture stress with maximum-rate
host screen writes and UART diagnostics. Capture overflow/callback-drop counters
must remain unchanged; after startup, DVI `video_errors` must not increase.
Measure stack high-water marks and CPU/DMA margins using an instrumented build.
Log faults; a desktop replay or clean UF2 build cannot substitute for this test.

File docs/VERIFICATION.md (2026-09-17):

# Verification record

Software verification on 2026-09-17; no assembled hardware or flashing was
available. A pass here does not close the physical acceptance gate.

Run from the repository root:

```sh
python3 tools/smoke.py
python3 tools/smoke.py --erc --firmware-from build/resumed
```

The first command needs Python 3, a C11 host compiler and pthreads. The second
also needs KiCad CLI and an existing configured Pico SDK build. It reads that
build's dependency paths, creates fresh build directories, and builds three
configurations: default IIe/passive demo, II/II+ with active demo, and video test
patterns. It checks all nine ELF/UF2/map sets and SRAM budgets. Build logs are
under `build/verify-*`; `build/last-verification.json` identifies the last matrix.
It does not flash or alter reference submodules.

| Check | Result | What it establishes |
|---|---|---|
| GPIO/IDC allocation | PASS | All 48 GPIOs allocated without collisions; video pairs and high-pin restrictions |
| KiCad ERC/netlists | PASS | Zero ERC violations; slot-powered direct-bus carrier 58, VGA 17, DVI 18 named nets checked |
| Clean firmware matrix | PASS | Three variants × three targets compile/link with warnings treated as errors |
| Passive capture logic | PASS | All 65,536 addresses, data/select/reset decoding, ordered block consumption, wrap and overwrite detection |
| Slot policy | PASS | Selection/address restrictions, C800 acquisition, other-slot release and CFFF release |
| Responder PIO logic | PASS | Actual 27-instruction source executes in a limited host interpreter; stale/zero tags, phase sweep, wrap and bounded release |
| Shadow traces | PASS | II/II+ and IIe bank precedence, IOUDIS/AN3, soft switches, initial unknown state, reset retention and loss invalidation |
| Concurrent shadow stress | PASS | 1,572,864 decoded writes while a desktop thread copies frames, including reset and epoch loss |
| Actual renderer replay | PASS | VGA token expansion and DVI TMDS decoding, output bounds, 640x480 frames, text/modes/page selection |
| Cross-backend text | PASS | Binary glyph positions match for normal/inverse/flashing text in both flash phases, 80 columns and alternate charset |
| Mixed/extended modes | PASS | Mixed text rows match text rendering; double modes produce distinct output; 80STORE suppresses page 2 |
| Physical capture/DMA timing | NOT RUN | Requires host or calibrated fixture and logic analyzer |
| Active slot timing/contention | NOT RUN | Requires qualified carrier, fixture and scope |
| Missing SYNC/live UART/reset/IRQ/NMI | NOT RUN | Hardware event behavior still needs measurement |
| Live capture plus VGA/DVI | NOT RUN | Desktop concurrency cannot establish RP2350 throughput or clock stability |
| Power sequencing/monitor compatibility | NOT RUN | See hardware validation procedure |

Renderer replay compiles the production renderer files with small host SDK and
output-sink substitutes. Undefined-behavior/bounds sanitizers are enabled; a
violation fails the run. Images are written to `build/replay/{IIE,IIPLUS}/`
as PPM files. Palette/artifact-color differences inherited from the two upstream
projects are allowed; text geometry and page-selection checks are exact.
There is no emulation of PIO synchronization, DMA arbitration or analog video.

Replay exposed and fixed unsigned-shift requirements in DVI double-hires and
II/II+ character-ROM flash semantics. Manual review added IIe IOUDIS gating for
AN3/DHIRES (Apple IIe Technical Reference Manual, table 2-10, p.29). Reset remains
conservative: RAM is retained and switches are reacquired from observed accesses.
A host redraw alone is insufficient if bank switches are still unknown; see the
explicit initialization sequence in the hardware validation guide.

Toolchain used: Pico SDK/picotool 2.2.0, ARM GCC 14.2.1, extracted newlib,
CMake Release configuration, ca65/ld65 for active-demo ROM, KiCad CLI 10.0.6.
Sources/revisions are in `fw/dependencies.json`. No PCB routing or fabrication
checks are included in this schematic-only release.

Carrier revision 0.2 (2026-09-17) removes the isolation/control circuit and
connects the bus directly. `python3 tools/smoke.py --erc` was rerun successfully
after the change. The carrier check verifies each direct slot/module pair and
the optional SYNC jumper against the GPIO contract. The firmware sources and
pin assignments are unchanged; the clean build matrix above was verified before
this schematic revision. Power-transition and all other physical results remain
NOT RUN under the revised operating assumptions.

Carrier revision 0.3 (2026-09-17) removes D2 and leaves module VBUS unconnected.
The slot supply feeds F1/D1/VSYS and H1.2 (WeAct's 5V pin). Carrier ERC and
connectivity checks cover the supply path, diode polarity, and USB disconnection;
there are now 58 named carrier nets. Module U2 removal and externally powered
USB flashing still require physical verification.

Carrier revision 0.4 changes wire labels and symbol presentation only. All 58
net endpoint sets match revision 0.3; carrier ERC and connectivity checks pass.

On 2026-09-18, all three schematics were reflowed to A4 landscape with larger
text (carrier 0.5, VGA/DVI 0.2). All named nets and endpoint sets match the
pre-layout versions, all three ERC/connectivity checks pass, and exported PDF
dimensions and rendered layouts were checked. This is a presentation change.

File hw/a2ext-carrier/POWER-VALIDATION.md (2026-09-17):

# Direct-bus power validation

Status: **OPEN — no physical qualification has been performed.** Carrier
revision 0.3 connects the Apple II bus directly to the module. The user approved
removing the CB3T switches and their supervisor/control circuit on 2026-09-17.
Revision 0.3 additionally removes USB power; slot input is the only supply.
This replaces the earlier isolation and dual-source procedures.

## Operating assumptions

- All operating power enters through slot pins 25/26. For off-host flashing,
  use a current-limited 5 V fixture at these pins and connect USB for data only.
  Do not hot-plug the card.
- RP2350 fault-tolerant digital inputs tolerate up to 5.5 V with IOVDD at
  3.3 V; their unpowered tolerance is only 3.63 V. GPIO2-34 carry the bus;
  ADC-capable GPIO40-47 are reserved for the daughterboard.
- There is no automatic bus disconnection during a module supply failure or
  RUN assertion. A live 5 V bus with the module unpowered is unsupported.
- Slot pin 25 feeds F1, then D1, then VSYS at module H1.2 (marked 5V).
  D1 retains reverse-current protection. Carrier D2 is removed, H1.1 (VBUS)
  is unconnected, and on-module U2 remains removed to disable USB power.
  The daughterboard +5V_DB is supplied through F1/F2 before D1.
- External UART/IDC devices must not drive an unpowered carrier or power it
  through signal pins. J2 supply pins are outputs.
- Verify the actual WeAct regulator, flash, and silicon revision. The vendor
  schematic does not identify the regulator or establish its load capability.

## Measurement procedure

Use a current-limited fixture before a host. Probe slot 5 V, VSYS (module 5V input),
module 3.3 V (IOVDD), and representative GPIOs: data, IRQ/NMI, PHI0, and SYNC.
Capture their relative voltage ramps and compare them against device limits
throughout transitions. Powering the regulator from the slot alone is not
proof of acceptable sequencing. Keep fixture outputs released until the
module is powered; characterize supply ramps before applying driven bus cycles.
Do not deliberately apply 5 V to an unpowered module to test for damage.

| Scenario | Required observation |
|---|---|
| Slot-powered startup, USB disconnected | Record relative slot, IOVDD, and GPIO ramps; establish input-voltage margins |
| Slot-powered shutdown | Record full decay; GPIO voltage remains within the applicable limits as IOVDD falls |
| Slow supply ramp and brownout | Establish the operating envelope and any interval outside the documented input conditions |
| RUN assertion/release with valid supplies | No unintended data/IRQ/NMI drive; pins remain physically connected |
| Fixture-powered BOOTSEL, card removed from host; USB data attached | Stable VSYS/3.3 V and boot-drive enumeration; fixture bus released |
| USB attached with fixture power absent, card removed from host | No powered module/HDMI rail; verify U2 removal and absence of D2 |
| Slot/fixture power present, USB disconnected | No supply feed into module VBUS/USB connector |
| UART/IDC attachment | No signal or supply back-power when either side is off |

Measure module/daughterboard current, regulator temperature, and diode/PTC
voltage drops at the intended load. Check HDMI +5 V independently of the module
input. Record board/module revision, silicon stepping, BOM, temperature,
supplies, probe settings, and waveform files with `PWR-01`/`PWR-02` results in
[the worksheet](../../docs/hardware-results.csv).

If normal transitions exceed ratings or show contention, record the failure
and revise the power arrangement before physical acceptance. Direct-bus
reference designs motivate this simpler circuit; they do not establish the
WeAct module's measured power behavior.

## Results

| Check | Status |
|---|---|
| Logical GPIO mapping and ADC exclusion | Automated check passed |
| All physical scenarios above | Not run — hardware/fixture unavailable |
| Regulator identity/current/thermal qualification | Not established |

Reference: [RP2350 electrical specifications, §12.2](https://datasheets.raspberrypi.com/rp2350/rp2350-datasheet.pdf).

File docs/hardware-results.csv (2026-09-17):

id | check | status | hardware_revision | firmware_commit | conditions | measurement | evidence
PWR-01 | power source and brownout matrix | NOT_RUN
PWR-02 | regulator identity current and temperature | NOT_RUN
BUS-01 | passive setup hold and loading | NOT_RUN
BUS-02 | 30 minute capture and induced overflow recovery | NOT_RUN
ACT-01 | active selected and unselected response timing | NOT_RUN
ACT-02 | late reply reset and FIFO fault contention | NOT_RUN
IO-01 | UART IRQ NMI and reset | NOT_RUN
IO-02 | missing and optional slot7 SYNC | NOT_RUN
VID-01 | shadow modes banking reset and redraw | NOT_RUN
VGA-01 | DAC levels sync and sustained output | NOT_RUN
DVI-01 | TMDS monitor stability and clock envelope | NOT_RUN
LOAD-01 | simultaneous capture video and diagnostics | NOT_RUN

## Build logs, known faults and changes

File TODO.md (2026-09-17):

# Remaining work

Reviewed 2026-09-17 at commit `b24fc41`.

The project is a software-verified schematic and firmware prototype. All seven
planned deliverables exist: carrier/VGA/DVI schematics, the shared library, and
demo/VGA/DVI firmware. Hardware acceptance remains open.

Work through the checklist in order. Mark an item complete only when its
acceptance criteria have been met and supporting evidence recorded. Keep
software verification separate from physical qualification.

## Verified baseline

The following command passed during this review:

```sh
python3 tools/smoke.py --erc --firmware-from build/resumed
```

- Capture, slot-response logic, shadow-memory, and concurrent-load tests passed.
- VGA/DVI renderer replay passed for IIe and II/II+.
- All three schematic ERC/connectivity checks passed with zero violations.
- Three clean build configurations × three firmware targets passed, including
  ELF/UF2/map artifact and SRAM checks.

All 12 physical checks in [the measurement worksheet](docs/hardware-results.csv)
remain `NOT_RUN`. PCB layout and fabrication outputs are outside the current
scope.

## Completed design revisions

- [x] Remove CB3T switches and related supervisors, BUS_GOOD/OE control, and
  local support components. Carrier revision 0.2 uses direct bus connections;
  update its schematic/PDF/BOM, checks, and operating documentation.

- [x] Use slot-only power: retain F1/D1 to module H1.2 (5V/VSYS), remove D2,
  leave VBUS unconnected, and keep on-module U2 removed. Update flashing to
  external fixture power with USB data only (carrier revision 0.3).

- [x] Improve carrier wire labels: Apple II signals, UART functions, and
  IDC pin/GPIO names, with readable placement and unchanged connectivity
  (carrier revision 0.4).

- [x] Enlarge text and reflow all three schematics onto A4 landscape pages
  (carrier 0.5, VGA/DVI 0.2), preserving electrical connectivity.

## Ordered checklist

- [ ] **1. Prepare hardware and a measurement fixture.** Assemble prototypes,
  verify the required module modifications, identify the module regulator and
  RP2350 silicon revision, and obtain the measurement equipment. Record hardware
  revisions and assembly evidence. See the
  [carrier assembly notes](hw/a2ext-carrier/README.md) and
  [bench procedure](docs/HARDWARE-VALIDATION.md).

- [ ] **2. Validate direct-bus power behavior.** Measure slot startup/shutdown,
  brownouts, USB power disconnection, back-power, current, and temperature. Complete
  the [power-validation matrix](hw/a2ext-carrier/POWER-VALIDATION.md) and resolve
  failures before host connection. Record `PWR-01` and `PWR-02` results.

- [ ] **3. Validate passive capture.** Measure bus loading and setup/hold margins.
  Pass at least 30 minutes of sustained capture, plus deliberately induced
  overflow and recovery tests. Record `BUS-01` and `BUS-02` results.

- [ ] **4. Qualify active responses.** Measure selected/unselected response
  deadlines, data release, and contention. Exercise late replies, reset, FIFO
  faults, and C800 ownership. Resolve the documented falling-edge/reset races
  if they violate host timing; address unacknowledged callback side effects
  where required. Record `ACT-01` and `ACT-02` results. See the
  [responder limitations](fw/a2ext-lib/README.md).

- [ ] **5. Validate live I/O and video modes.** Exercise UART, IRQ/NMI, reset,
  optional/missing SYNC, shadow acquisition, banking, redraw, and II/II+/IIe
  display modes. Record `IO-01`, `IO-02`, and `VID-01` results.

- [ ] **6. Qualify VGA and DVI output.** Measure VGA DAC levels and sync timing;
  investigate the sync-line TODO in `fw/a2ext-vga/vga.c` (`vga_prepare_frame`).
  Verify DVI signal and monitor compatibility, reconnect behavior, and
  experimental 252 MHz stability across the intended operating envelope.
  Use direct daughterboard mating as the baseline. Record `VGA-01` and `DVI-01`
  results; also qualify the active demo's experimental clock during its tests.

- [ ] **7. Run combined-load acceptance.** For each video backend, sustain
  capture, video, and diagnostics together for at least 30 minutes. Measure
  stack high-water marks and CPU/DMA service margins. Require no capture
  overflows or callback drops and no increasing DVI missed-scanline count after
  startup. Record `LOAD-01` results.

- [ ] **8. Update acceptance records and project status.** Record measurements,
  conditions, firmware identity, and evidence in
  [hardware-results.csv](docs/hardware-results.csv) as each test is performed.
  Keep [PROGRESS.md](PROGRESS.md), the verification record, and README in sync
  with actual outcomes, leaving any unmet gates explicitly open.

## Supporting records

- [Implementation plan](PLAN.md)
- [Progress record](PROGRESS.md)
- [Software verification and limitations](docs/VERIFICATION.md)
- [Physical validation procedure](docs/HARDWARE-VALIDATION.md)
- [Measurement worksheet](docs/hardware-results.csv)
- [Resource and timing budgets](docs/resources.md)

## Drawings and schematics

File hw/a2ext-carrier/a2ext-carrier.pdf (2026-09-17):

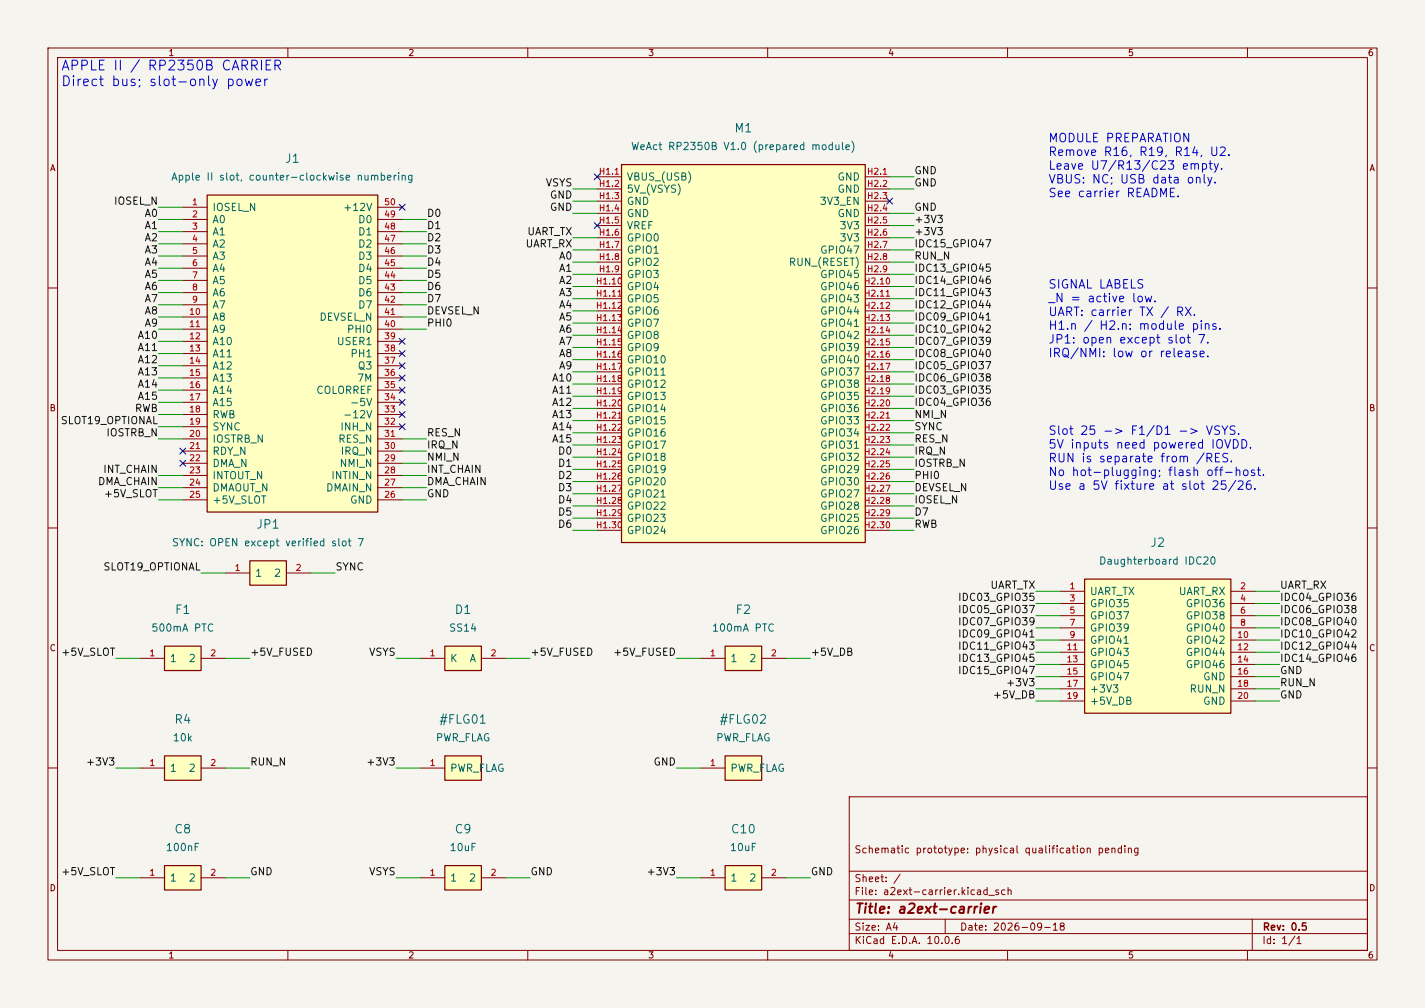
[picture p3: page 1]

APPLE II / RP2350B CARRIER
Direct bus; slot-only power

MODULE PREPARATION
Remove R16, R19, R14, U2.
Leave U7/R13/C23 empty.
VBUS: NC; USB data only.
See carrier README.

Apple II slot, counter-clockwise numbering

SIGNAL LABELS
_N = active low.
UART: carrier TX / RX.
H1.n / H2.n: module pins.
JP1: open except slot 7.
IRQ/NMI: low or release.

Slot 25 -> F1/D1 -> VSYS.
5V inputs need powered IOVDD.
RUN is separate from /RES.
No hot-plugging; flash off-host.
Use a 5V fixture at slot 25/26.

SYNC: OPEN except verified slot 7

Schematic prototype: physical qualification pending

Size: A4 | Rev: 0.5
KiCad E.D.A. 10.0.6 | Id: 1/1

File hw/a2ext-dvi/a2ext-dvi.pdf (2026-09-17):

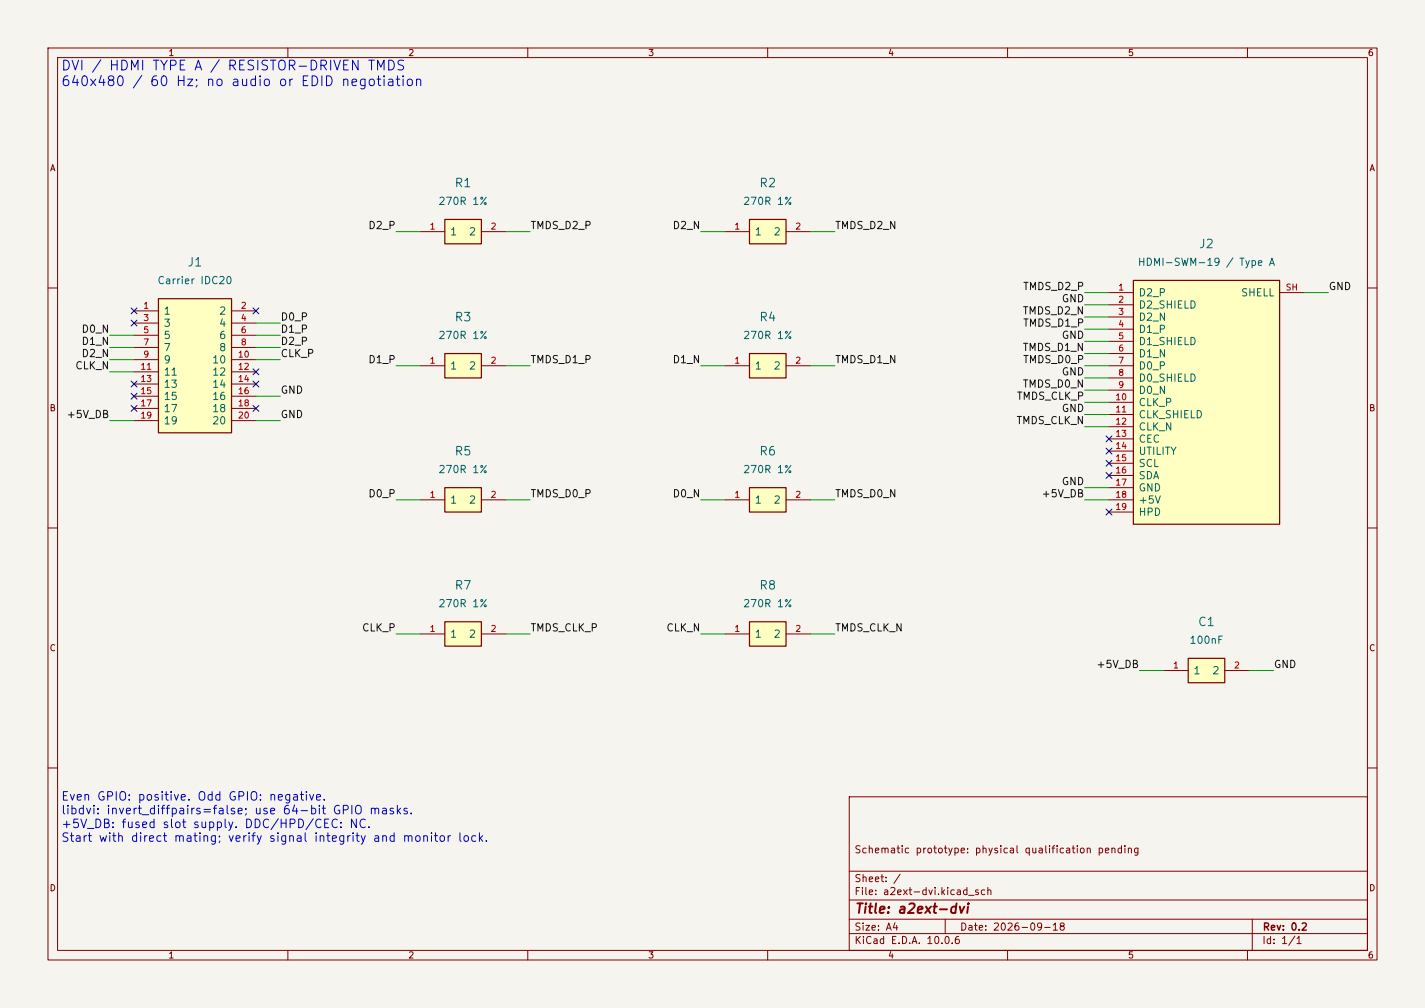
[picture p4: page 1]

DVI / HDMI TYPE A / RESISTOR-DRIVEN TMDS
640x480 / 60 Hz; no audio or EDID negotiation

Even GPIO: positive. Odd GPIO: negative.
libdvi: invert_diffpairs=false; use 64-bit GPIO masks.
+5V_DB: fused slot supply. DDC/HPD/CEC: NC.
Start with direct mating; verify signal integrity and monitor lock.

Schematic prototype: physical qualification pending

Size: A4 | Rev: 0.2
KiCad E.D.A. 10.0.6 | Id: 1/1

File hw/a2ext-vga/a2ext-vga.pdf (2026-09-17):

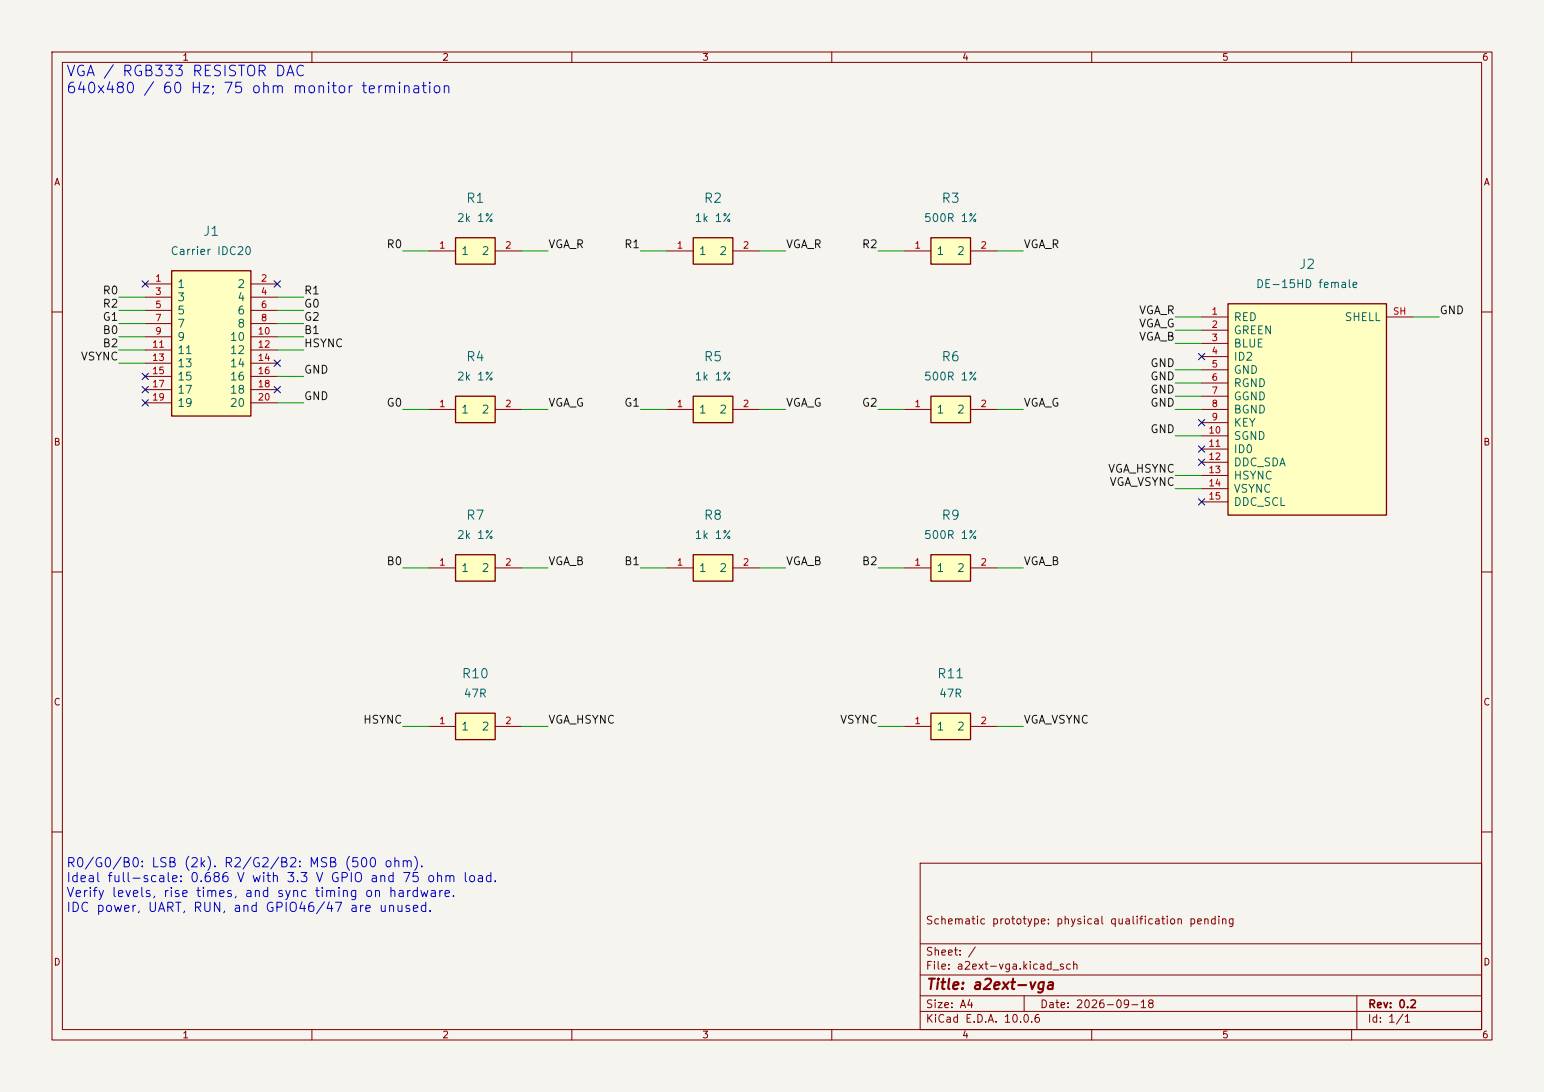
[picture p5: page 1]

VGA / RGB333 RESISTOR DAC
640x480 / 60 Hz; 75 ohm monitor termination

R0/G0/B0: LSB (2k). R2/G2/B2: MSB (500 ohm).
Ideal full-scale: 0.686 V with 3.3 V GPIO and 75 ohm load.
Verify levels, rise times, and sync timing on hardware.
IDC power, UART, RUN, and GPIO46/47 are unused.

Schematic prototype: physical qualification pending

Size: A4 | Rev: 0.2
KiCad E.D.A. 10.0.6 | Id: 1/1

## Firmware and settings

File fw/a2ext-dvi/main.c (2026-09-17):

#include "hardware/clocks.h"
#include "hardware/irq.h"
#include "pico/stdlib.h"
#include "a2ext_pins.h"
#include "runtime.h"
#include "applebus/buffers.h"
#include "render/render.h"
#include "fonts/textfont.h"
#include <string.h>
struct dvi_inst dvi0;
uint8_t color_mode;
bool mono_rendering, color_support, reload_colors;
static struct dvi_serialiser_cfg serial = {
    .pio=pio1, .sm_tmds={0,1,2},
    .pins_tmds={A2EXT_GPIO_DVI_D0_P,A2EXT_GPIO_DVI_D1_P,A2EXT_GPIO_DVI_D2_P},
    .pins_clk=A2EXT_GPIO_DVI_CLK_P, .invert_diffpairs=false,
};
int main(void) {
    /* Experimental: 252 MHz exceeds the rated 150 MHz. No voltage override. */
    set_sys_clock_khz(252000,true);
    video_capture_start();
#ifdef APPLE_MODEL_IIPLUS
    memcpy(character_rom,textfont_iiplus_us,CHARACTER_ROM_SIZE);
#else
    memcpy(character_rom,textfont_iie_us_enhanced,CHARACTER_ROM_SIZE);
#endif
    DVI_INIT_RESOLUTION(640);
    tmds_color_load();
    dvi0.timing=&dvi_timing_640x480p_60hz; dvi0.ser_cfg=&serial;
    uint lock=spin_lock_claim_unused(true);
    dvi_init(&dvi0,lock,lock);
    dvi_register_irqs_this_core(&dvi0,DMA_IRQ_0);
    irq_set_priority(DMA_IRQ_0, PICO_DEFAULT_IRQ_PRIORITY);
    dvi_start(&dvi0);
    for (;;) {
        soft_switches=atomic_load(&video_shadow.flags);
        video_snapshot(apple_memory,aux_memory);
        render_frame(); video_output_errors(dvi0.scanline_errors); video_poll();
    }
}

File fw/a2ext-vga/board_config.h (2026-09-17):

#pragma once
#include "a2ext_pins.h"
#define CONFIG_SYSCLOCK 126.0
#define CONFIG_PIN_HSYNC A2EXT_GPIO_VGA_HSYNC
#define CONFIG_PIN_VSYNC A2EXT_GPIO_VGA_VSYNC
#define CONFIG_PIN_RGB_BASE A2EXT_GPIO_VGA_R0
#define CONFIG_VGA_PIO pio1
#define CONFIG_VGA_SPINLOCK_ID 31

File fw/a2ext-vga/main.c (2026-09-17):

#include "hardware/clocks.h"
#include "pico/stdlib.h"
#include "runtime.h"
#include "buffers.h"
#include "render.h"
#include "vga.h"
#include "textfont/textfont.h"
#include <string.h>
static void snapshot(void) {
    uint32_t f=atomic_load(&video_shadow.flags);
    soft_switches=f&15;
    soft_80col=f&A2EXT_80COL; soft_80store=f&A2EXT_80STORE;
    soft_altcharset=f&A2EXT_ALTCHAR; soft_dhires=f&A2EXT_DHIRES;
    soft_video7_mode=VIDEO7_MODE_140x192;
    video_snapshot(main_memory,aux_memory);
}
int main(void) {
    set_sys_clock_khz(126000,true);
    video_capture_start();
#ifdef APPLE_MODEL_IIPLUS
    memcpy(character_rom,textfont_iiplus_us,sizeof character_rom);
#else
    memcpy(character_rom,textfont_iie_us_enhanced,sizeof character_rom);
#endif
    render_init(); vga_init();
    for (;;) { snapshot(); render_frame(); video_poll(); }
}

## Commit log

2026-09-16 docs: identify WeAct carrier module and connector geometry
2026-09-16 docs: specify WeAct bus pin preparation and checks
2026-09-16 feat: allocate PIO resources and assemble passive capture
2026-09-16 feat: add isolated carrier schematic and connectivity checks
    [BOM.csv, a2ext-carrier.kicad_sch]
2026-09-16 docs: define carrier power qualification gate
2026-09-16 feat: add VGA daughterboard schematic and DAC calculations
    [BOM.csv, a2ext-vga.kicad_sch]
2026-09-16 feat: add DVI daughterboard schematic and TMDS mapping
    [BOM.csv, a2ext-dvi.kicad_sch]
2026-09-16 feat: capture full Apple II bus cycles with DMA loss detection
2026-09-16 feat: define latched bus APIs and deferred UART reset sync callbacks
    [a2ext.c]
2026-09-16 Implement experimental tagged slot responder and demo
    [firmware.cfg]
2026-09-17 Publish hardware acceptance procedures and measurement worksheet
    [hardware-results.csv]
2026-09-17 Document prototype build usage compatibility and open hardware gates
2026-09-17 Simplify carrier to direct bus and slot power; improve schematic readability
    Remove bus isolation and USB power circuitry, clarify signal labels, and reflow all schematics onto A4 landscape with larger text. Update PDFs, BOMs, connectivity checks, operating documentation, pro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
    [BOM.csv, a2ext-carrier.kicad_sch, a2ext-dvi.kicad_sch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]
2026-10-12 Add two-layer prototype PCBs and Gerber packages for all boards
2026-10-12 Revise all prototype PCBs for through-hole assembly
